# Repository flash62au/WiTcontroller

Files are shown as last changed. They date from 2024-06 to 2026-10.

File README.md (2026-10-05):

# WiTcontroller

A WiTcontroller is a simple DIY, handheld controller that talks to a WiThrottle Server (JMRI, DCC-EX EX-CommandStation, Digitrax LnWi and many others) using the WiThrottle protocol to control DCC model trains. 

> [See full change log/ version history](change_log.md)

---

## Why WiTcontroller?

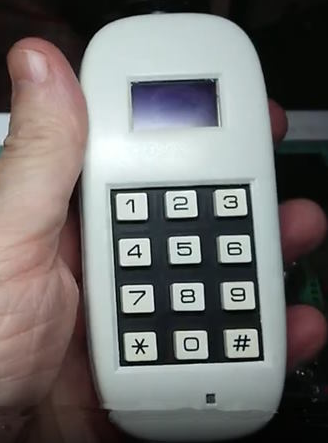
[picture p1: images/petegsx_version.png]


There are a number of excellent DIY DCC controllers available, but most require a lot of components and a lot of soldering.  I wanted to create the simplest possible controller so that it would be as easy (as possible) to make one.

In its basic form, the WiTcontroller uses only four components plus a battery.  You can even put it together without soldering, though I don't recommend that for long term use.

While the basic form is simple, the design is flexible and you can add several additional components if you wish.

[See a video of it in use here.](https://youtu.be/RKnhfBCP_SQ)  
[and another...](https://www.youtube.com/watch?v=1w7H2OvP8Jg) (from GingeAngles)
[and another...](https://youtu.be/69rTwZ4NM7E?si=bjXsFOhbpBvZsjaS) (from Sumner)

## The name

*WiTcontroller* is a contraction of 'WiThrottle Controller' as it uses the WiThrottle Protocol for communications with the server.  I pronounce it as 'Wit Controller', but you can pronounce it however you like.😊

> [!NOTE]
>
> * 'WiThrottle' is a trademark owned by Brett Hoffman. It is also an iOS app developed by Brett Hoffman.
> * The 'WiThrottle protocol' is a communications protocol developed by Brett Hoffman.  It is used by **WiTcontroller**, JMRI, Engine Driver, the WiThrottle app plus a number of other apps and DCC Command Stations. References in this document to a 'WiThrottle Server', refer to any server that can communicate using the 'WiThrottle protocol'.
 
---

## Index / Contents

* [Prerequisites](#prerequisites)
* [Building](#building)
* [Loading the Code](#loading-the-code)
* [Using WiTcontroller](#using-witcontroller)
* [Allowed Actions](#allowed-assignments-for-the-0-9-keys-andor-additional-buttons)
* [Options and Extras](#options-and-extras)
* [Contact Me](#contact-me) <br/> <br/>
* [Modifying the code](#modifying-the-code)
* [Change Log](#change-log)

<br/>
<hr style="border: none; height: 4px; background-color: #007bff; border-radius: 2px;">

## Prerequisites

1. Some basic soldering skills.

    The components will work if just plugged together using jumpers, but they take a lot of space that way, so soldering them together is advised to make it more hand held.

2. Loading the code (sketch) requires downloading of one of the IDEs, this sketch, the libraries, etc. so some experience with Arduinos is helpful, but not critical.

3. A WiThrottle Server to connect to. WiTcontroller will work with any WiThrottle Server. e.g.

    * **JMRI**
    * **DCC-EX EX-CommandStation**
    * **MRC WiFi**
    * **Digitrax LnWi**
    * **NCE WiFiTrax**
    * and others

    Note that there seems to be an issue with the **YaMoRC Command Station** that I am still working on.  See the notes for the DEFAULT_HEARTBEAT_PERIOD define below.

<br/>
<hr style="border: none; height: 4px; background-color: #007bff; border-radius: 2px;">

## Building

### Required Components

1. **WeMos Lite LOLIN32**  (ESP32 Arduino with LiPo charger) ([Example](https://www.ebay.com.au/itm/284800618644?hash=item424f709094:g:-soAAOSwHslfC9ce&frcectupt=true)) 

    Note: *Any ESP32 will work but the pinouts may need to be adjusted, and a separate LiPo charger may be required*

> [!CAUTION]
> I have reports of some of the versions of this board with the USB-C connectors having problems with the WiFi.  Some are clearly fine, but others are not. I am still investigating this, but I would recommend avoiding the USB-C version for now.

2. **3x4 Keypad**  ([Example](https://www.jaycar.com.au/12-key-numeric-keypad/p/SP0770?pos=2&queryId=20aedf107668ad42c6fe1f8b7f7a9ca7)) 

    Notes:

    * Alternately a 4x4 keypad can also be used (see optional components below)
    * Different keypad manufacturers may arrange the pins on the base of the keypad differently.*** See notes in the [Default Pins for the keypads](#default-pins-for-the-keypads) section below.

3. **KY-040 Rotary Encoder Module** ([Example](https://www.aliexpress.com/item/1005003946689694.html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)) 

    Notes:

    *The **EC11 rotary encoder** will also work, but requires a small configuration change in ``config_buttons.h`` (see below)*

4. **OLED Display** 0.96" 128x64 I2C IIC SSD1306 ([Example](https://www.ebay.com.au/itm/273746192621?ssPageName=STRK%3AMEBIDX%3AIT&_trksid=p2060353.m2749.l2649))

    Notes:

    * *The code for the one of the common 1.3" displays is also included (see below).*
    * *Some OLED displays up to 2.4 inch will also work (see below)*

5. **Polymer Lithium Ion Battery LiPo** 400mAh (or larger) 3.7V 502535 JST Connector. ([500mAh Example](https://www.ebay.com.au/itm/133708965793?hash=item1f21ace7a1:g:tlwAAOSwfORgYqYK)) 

    Notes:

    * Any capacity battery will work. A 400mAh will give about 6 hours of run time.*
    
> [!CAUTION]
> *I have found that some batteries come with the positive and negative leads the other way around to the terminals on the ESP32.* **Check they are correct before plugging it in!** <br/> <br/> The polarity of the battery is easy to swap, by getting a knife blade under the small tabs on the plastic connector and pulling each male socket out. Take extreme care. **DO NOT SHORT THE TERMINALS.**

6. **A Case to put it in**. Links to a few different designs are below, but any box will do. My case was 3d printed for me (see below).

7. **A Knob** ([Example](https://www.jaycar.com.au/35mm-knob-matching-equipment-style/p/HK7766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))

8. **Wire** - If you plan to solder the connections, which is the recommended approach, then stranded, coloured wire is advisable.  ([Example](https://www.jaycar.com.au/rainbow-cable-16-core-sold-per-metre/p/WM4516))

### Optional Components

9. *Optional:* **A power switch**. Push button or toggle. <br/> The battery in WiTcontroller will last a week or two in deep sleep, but you may wish to add a power switch on the positive feed of the battery if you expect to leave it unused for long periods.

10. *Optional:* You can use a **4x4 keypad** instead of the 3x4 keypad. <br/> Note: You will need to make a small configuration change in ``config_buttons.h`` for this to work correctly.

11. *Optional:* Up to eleven (11) additional **push buttons** can be added directly to the ESP32, each with their own independent commands. ([Example](https://www.jaycar.com.au/red-miniature-pushbutton-spst-momentary-action-125v-1a-rating/p/SP0710))

12. *Optional:* **A 1.3" or 2.4" OLED Display** (128x64) can be used instead of the 0.96" OLED Display 128x64 ([Example](https://www.aliexpress.com/item/32683094040.html?spm=a2g0o.order_list.order_list_main.110.25621802jRBB7y)) Note: You will need to make a minor change in the config file for this to work correctly.

13. *Optional:* Though not recommended, it is possible to use a **Potentiometer** instead of the Rotary Encoder for throttle control.  The code supports it if you make the appropriate configuration changes in ``config_buttons.h``.   However this has had only limited testing. <br/> This is documented to some degree in [config_buttons_example.h](config_buttons_example.h) if you wish to try it.

### Pinouts

*Standard Configuration Pinouts*  <br/> This is the simplest form of the WiTcontroller
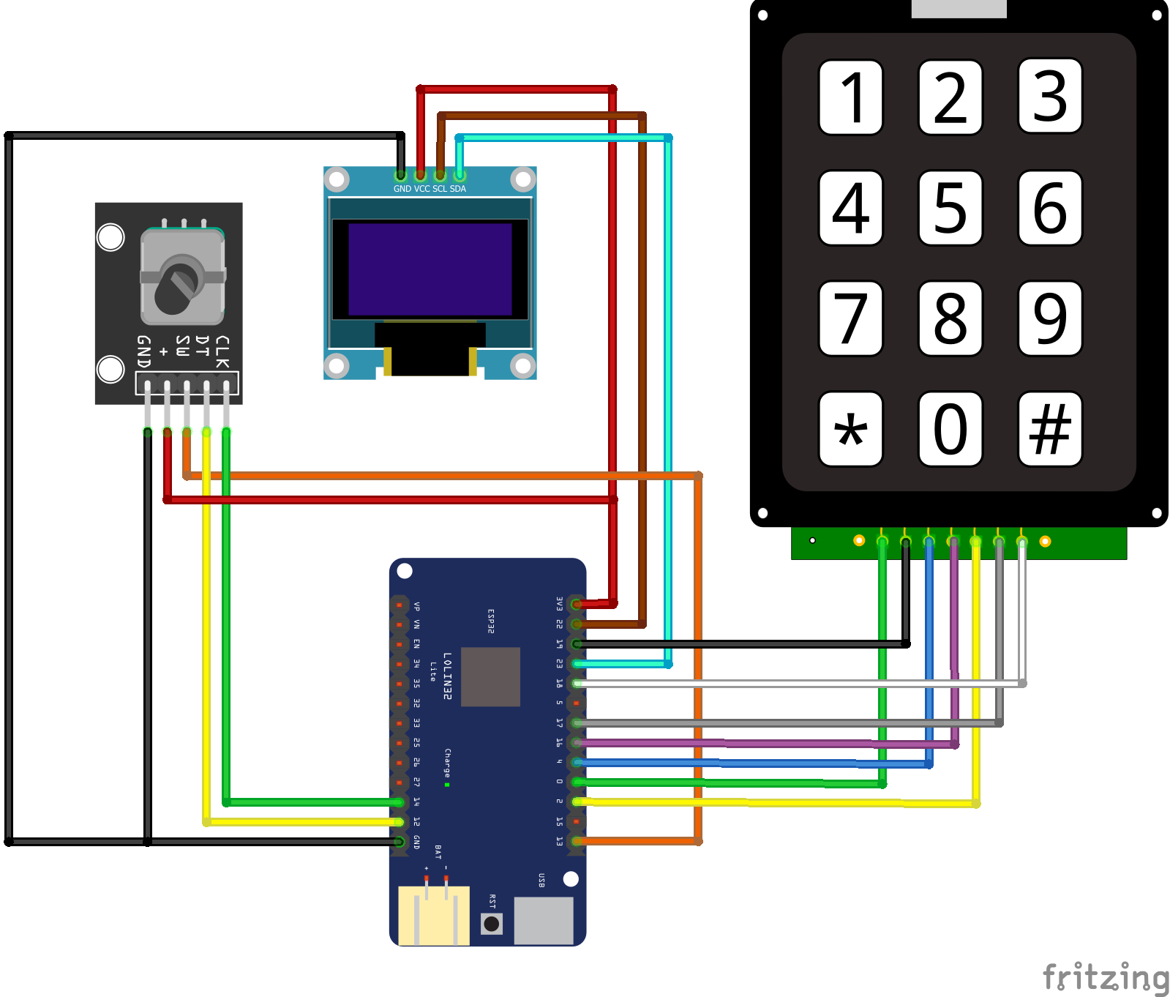
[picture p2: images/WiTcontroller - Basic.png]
Assembly diagram


*Pinouts for Optional Additional Buttons*
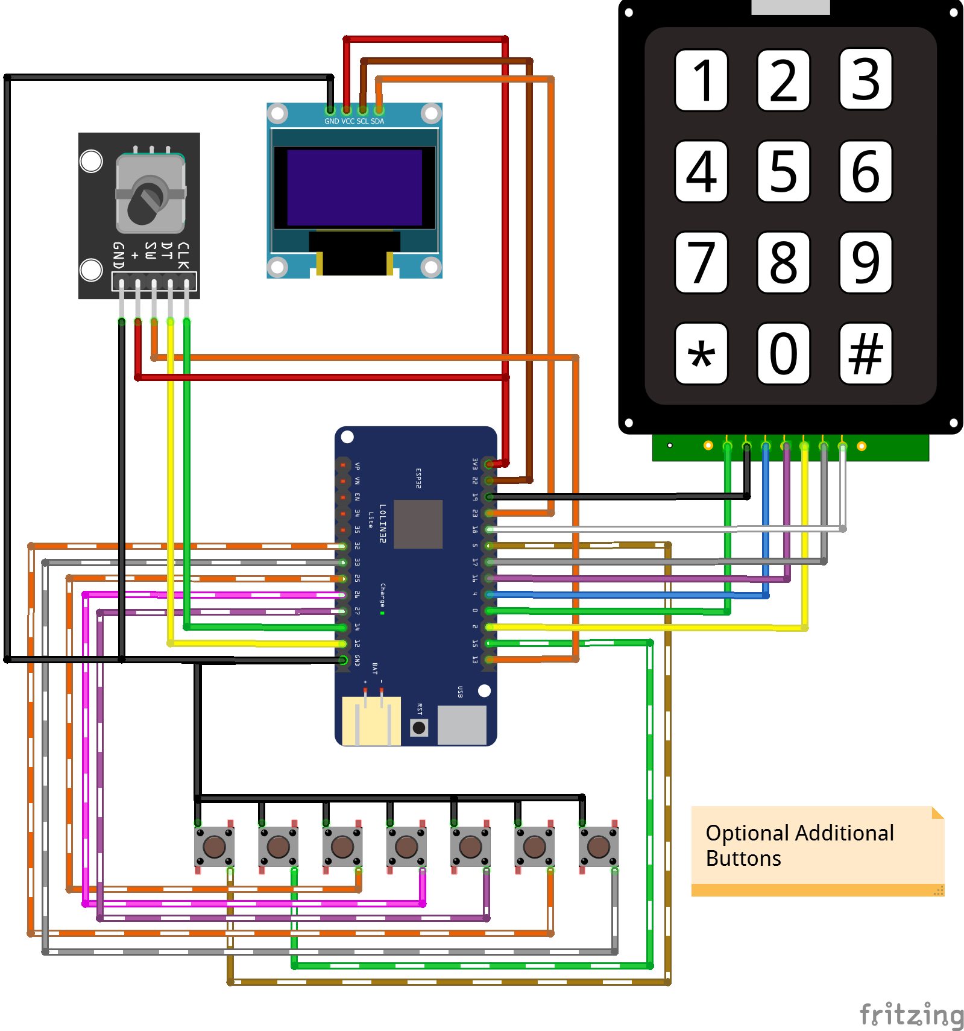
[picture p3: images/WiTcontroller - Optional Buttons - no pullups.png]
Assembly diagram - Optional Additional Buttons


*Pinouts for Optional Additional Buttons - With Pullups*
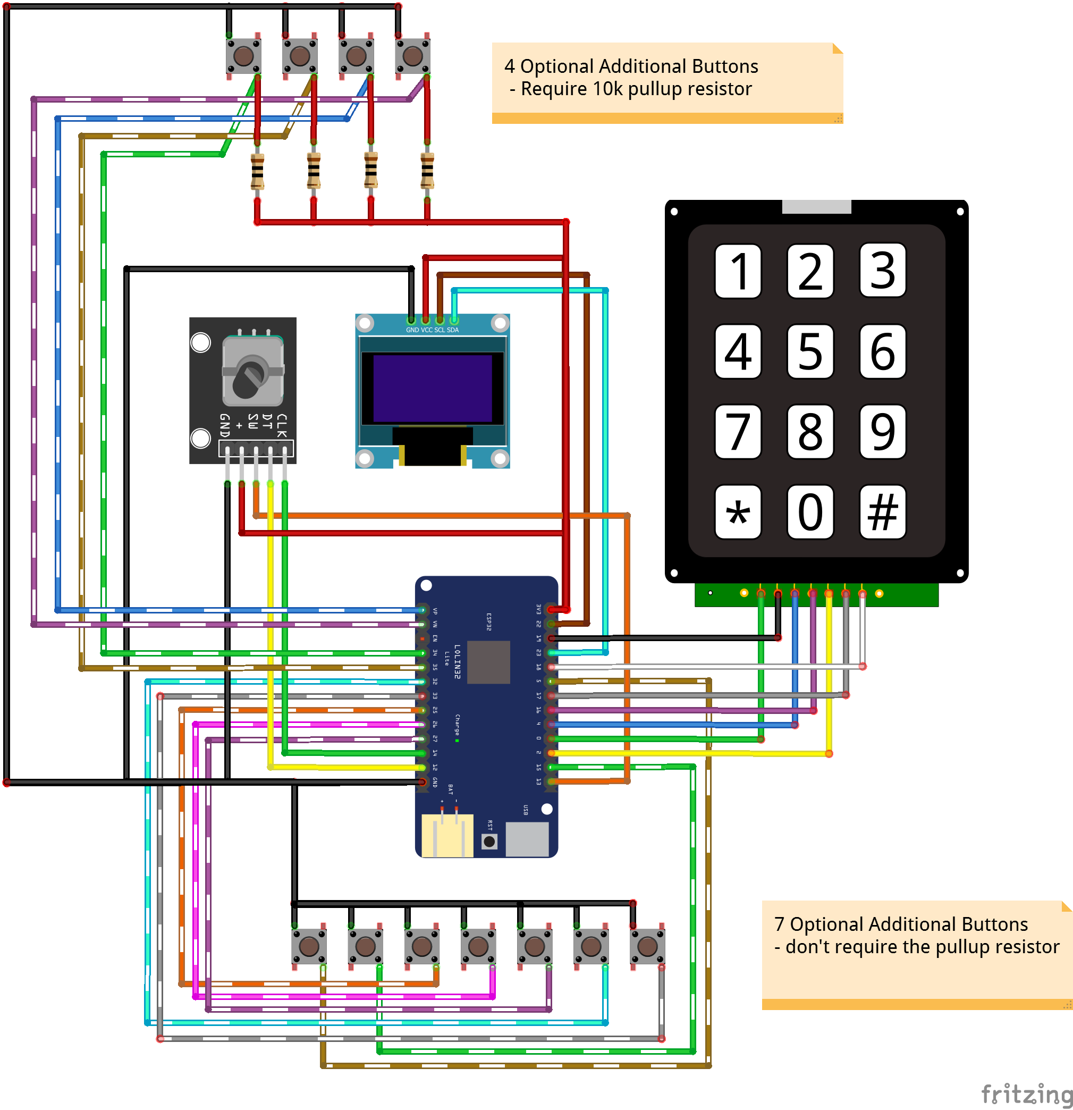
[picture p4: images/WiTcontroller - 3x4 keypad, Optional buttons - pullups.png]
Assembly diagram - Optional Additional Buttons - With Pullups


*Pinouts for Optional 4x4 keypad and Additional Buttons - without pullup resistors*
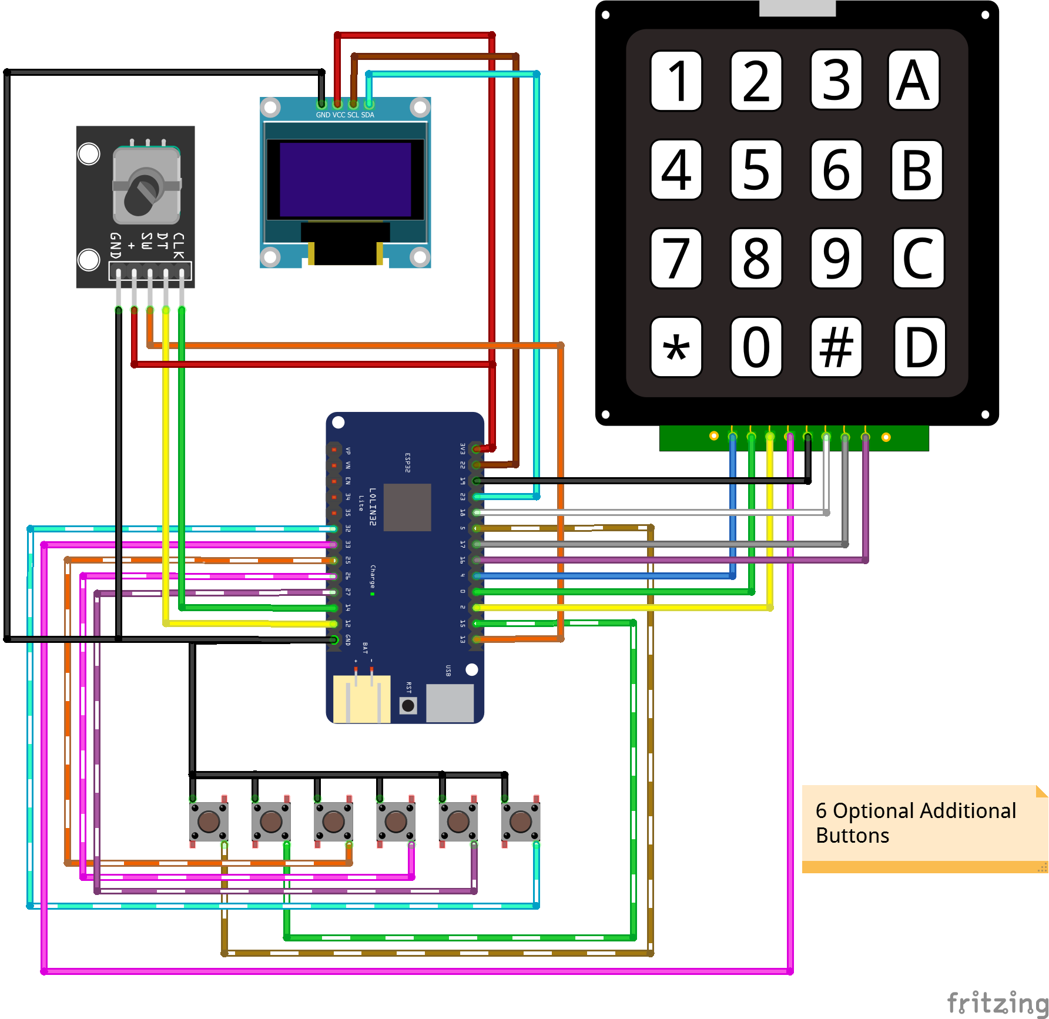
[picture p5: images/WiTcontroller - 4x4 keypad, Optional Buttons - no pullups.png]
Assembly diagram - 4x4 keypad and Optional Additional Buttons


*Pinouts for Optional Battery Monitor and Additional Buttons*
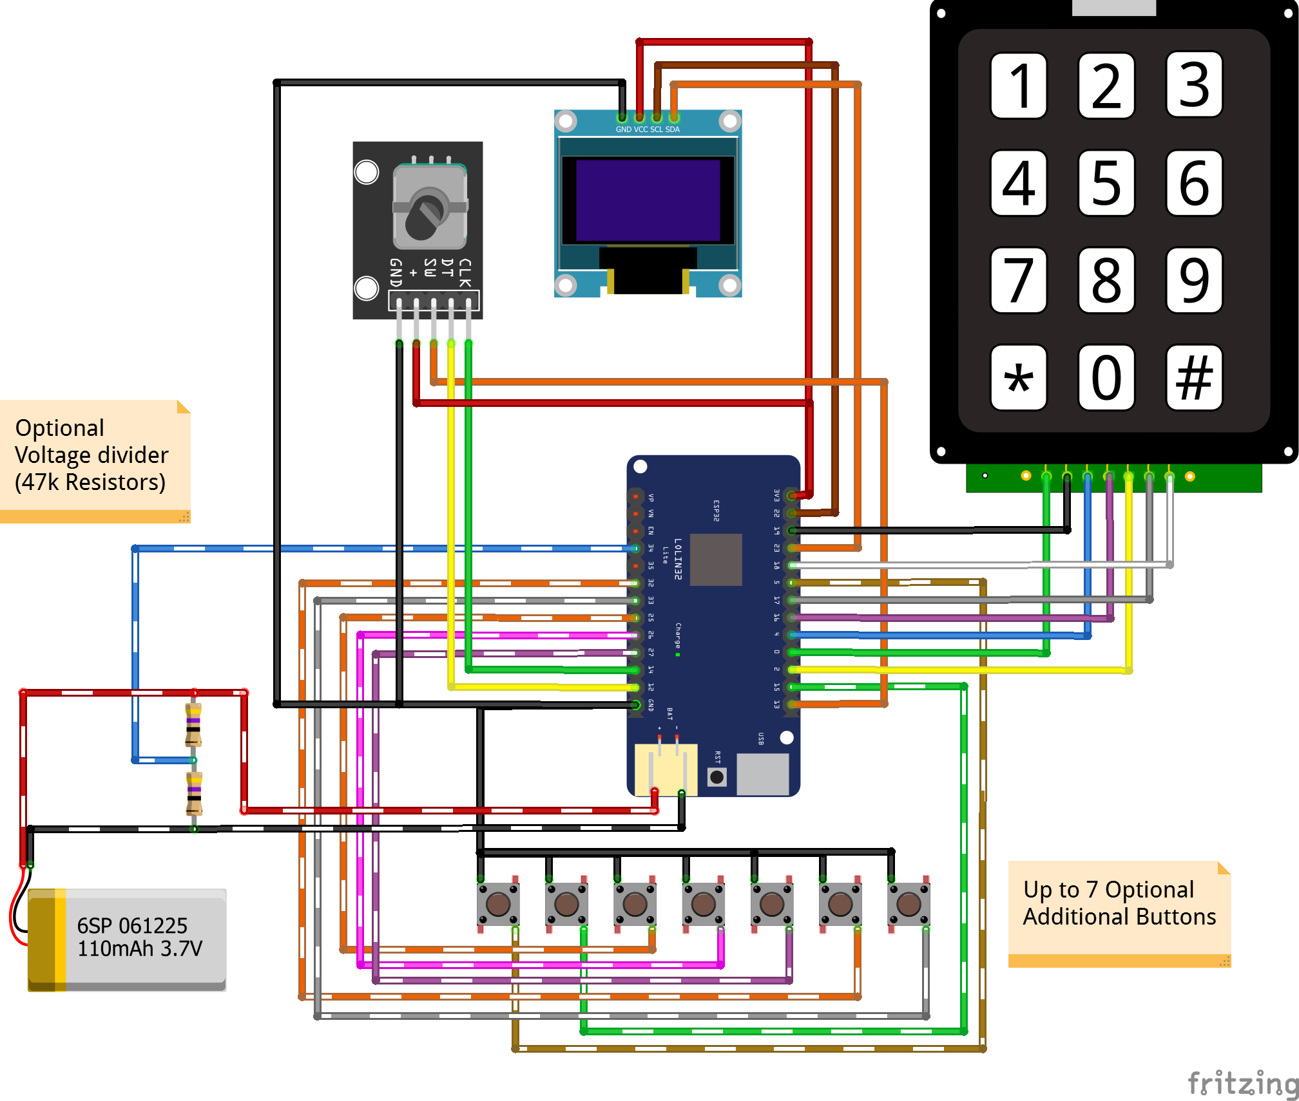
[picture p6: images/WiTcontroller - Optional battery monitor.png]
Assembly diagram - Optional Battery Monitor and Additional Buttons


> [!WARNING]
> *Different keypad manufacturers may arrange the pins on the base of the keypad differently to the examples above.* <br/> See notes in the [Default Pins for the keypads](#default-pins-for-the-keypads)  section below.

---

### Default Pins

#### Default ESP32 and WiTcontroller pins

<details>

<summary>Click to expand to see a table of the default pinouts</summary>

```
         3x4    4x4    OLED Encoder  Additional   Battery
    Pin Keypad Keypad                  Buttons     Test
     0    C1     C1                             
N/A  1                                       
     2    C2     C2                             
N/A  3                                     
     4    C0     C0                             
     5                                  AB0     
N/A  6                                      
N/A  7                                      
N/A  8                                      
N/A  9                                      
N/A 10                                       
N/A 11                                       
    12                        DT               
    13                        SW               
    14                        CLK               
    15                                  AB1     
    16     R3     R3                             
    17     R2     R2                             
    18     R1     R1                             
    19     R0     R0                             
N/A 20                                       
N/A 21                                       
    22                  SLC                     
    23                  SDA                     
N/A 24                                       
    25                                  AB2     
    26                                  AB3     
    27                                  AB4     
N/A 28                                       
N/A 29                                       
N/A 30                                       
N/A 31                                       
N/A 32                                  AB5     
    33          C3                      AB6     
    34                                  AB7 *        BT
    35                                  AB8 *     
VP  36                                  AB9 *     
N/A 37                                       
N/A 38                                       
VN  39                                  AB10*     

* Requires an external pullup resistor
```
</details>

<br />

#### Default Pins for the keypads

<details>

<summary>Click to expand to see a table of the Default Pins for the keypads</summary>

```
3x4 Keypad - Left to Right    4x4 keypad - Left to Right
 C1 PIN 0                      C0 PIN 4
 R0 PIN 19                     C1 PIN 0
 C0 PIN 4                      C2 PIN 2
 R3 PIN 16                     C3 PIN 33
 C2 PIN 2                      R0 PIN 19
 R2 PIN 17                     R1 PIN 18
 R1 PIN 18                     R2 PIN 17
                               R3 PIN 16

Cx = Column x      Rx = Row x

WARNING:
Different keypad manufacturers may arrange the pins on the 
base of the keypad differently to those listed above.
So it is important to make sure the pins on the keypad are 
correctly identified and adjusted as needed.

```
 
</details>

---

### Case

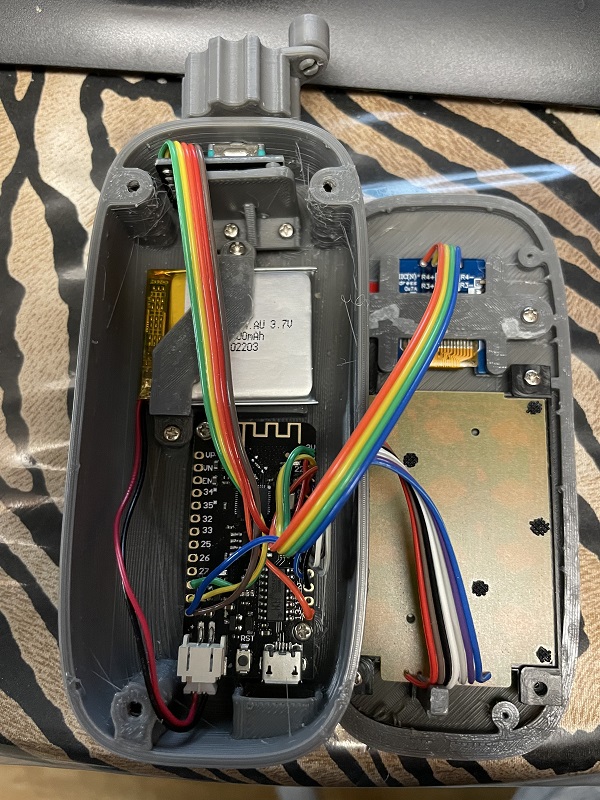
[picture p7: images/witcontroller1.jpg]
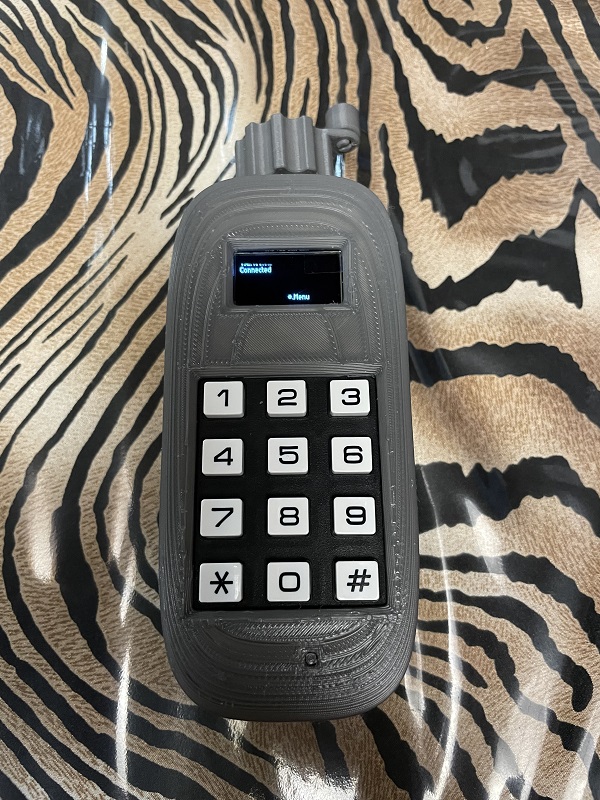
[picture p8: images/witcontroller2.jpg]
 

My case was 3D Printed for me by peteGSX (See the [Thingiverse.](https://www.thingiverse.com/thing:5440351) )

* The 3x4 keypad petGSX designed the case for came from Jaycar and is slightly narrower than the one you see in the 'deconstructed' view in the video above.
* The case requires about a dozen M2x4mm screws

---

### Variations

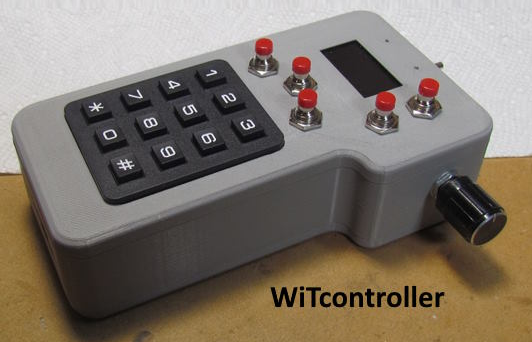
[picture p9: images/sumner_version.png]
 <br/>
See [*sumner* version](https://1fatgmc.com/RailRoad/DCC/WiTcontroller-Index.html).

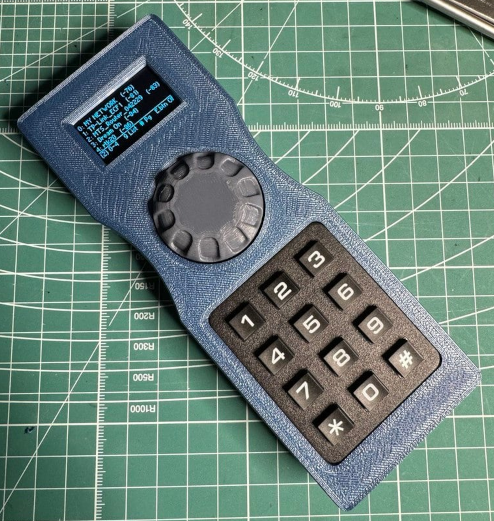
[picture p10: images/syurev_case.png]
 <br/>
syurev version. See [Thingiverse](https://www.thingiverse.com/thing:6541187) or [cults3d](https://cults3d.com/en/3d-model/gadget/case-for-dccexcontroller-witcontroller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)

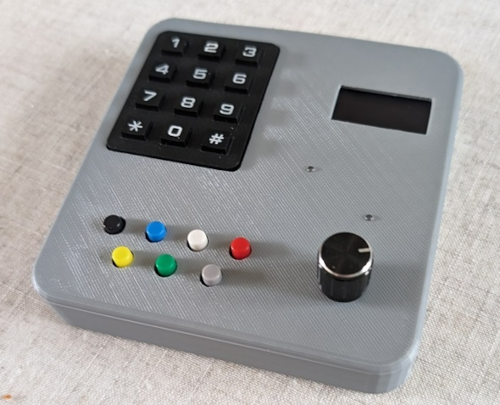
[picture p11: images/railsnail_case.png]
 <br/>
Railsnail version. See [RMweb](https://www.rmweb.co.uk/forums/topic/186297-project-a-witcontroller-wireless-throttle-to-control-my-dcc-ex-commandstation/).

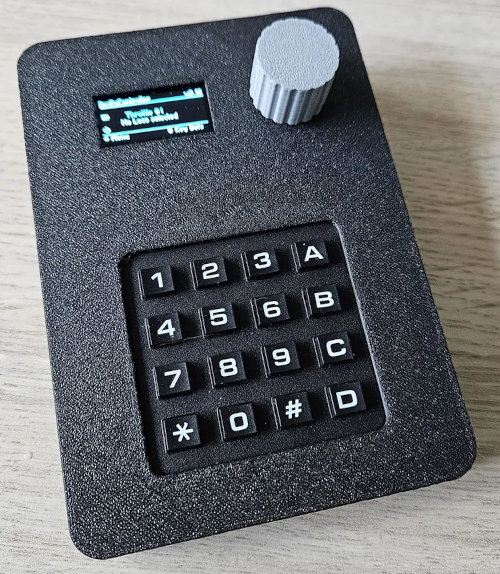
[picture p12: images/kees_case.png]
 <br/>
kees version. See [printables](https://www.printables.com/model/907658-dccexcontroller-witcontroller).

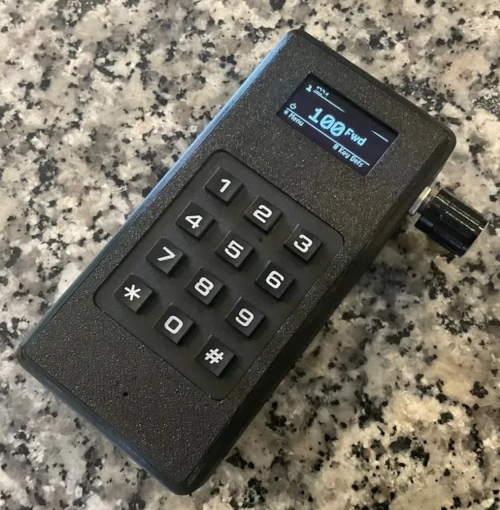
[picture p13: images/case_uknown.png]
 <br/>
Unknown author. See [Thingiverse](https://makerworld.com/en/models/819825).

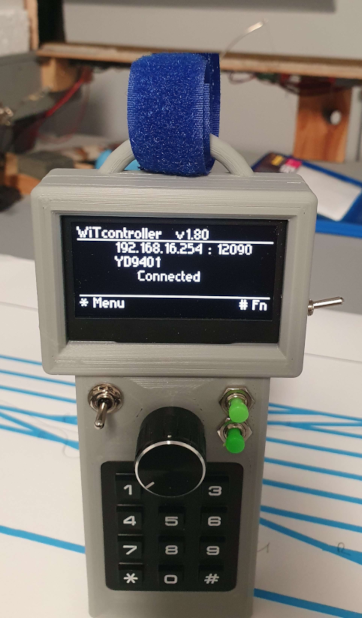
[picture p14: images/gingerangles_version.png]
 <br/>
*gingerangles* version with 2.4 inch screen...
gingerangels can be contacted on the DCC-EX Discord server.
[Discord Invite](https://discord.gg/8ghsjsBup8) - 
[specific message](https://discord.com/channels/713189617066836079/735156882511102033/1316646832297742380)

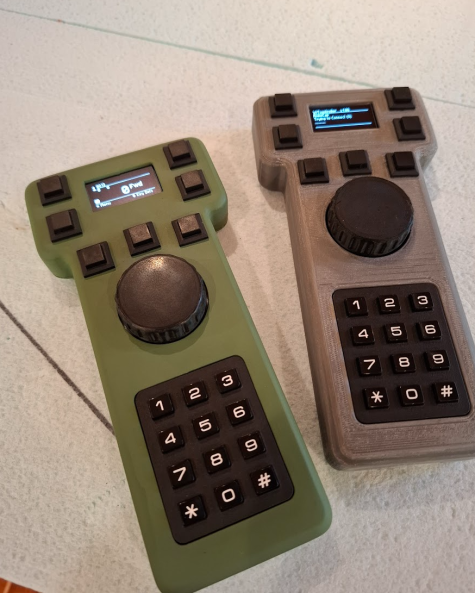
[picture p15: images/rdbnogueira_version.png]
 <br/> 
rdbnogueira version. See [Thingiverse](https://www.thingiverse.com/thing:6956982)

 <br/>
David Virgo's version using the EC11 encoder. See [GitHub](https://github.com/dvirgo62/Printed-case-for-witcontroller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)

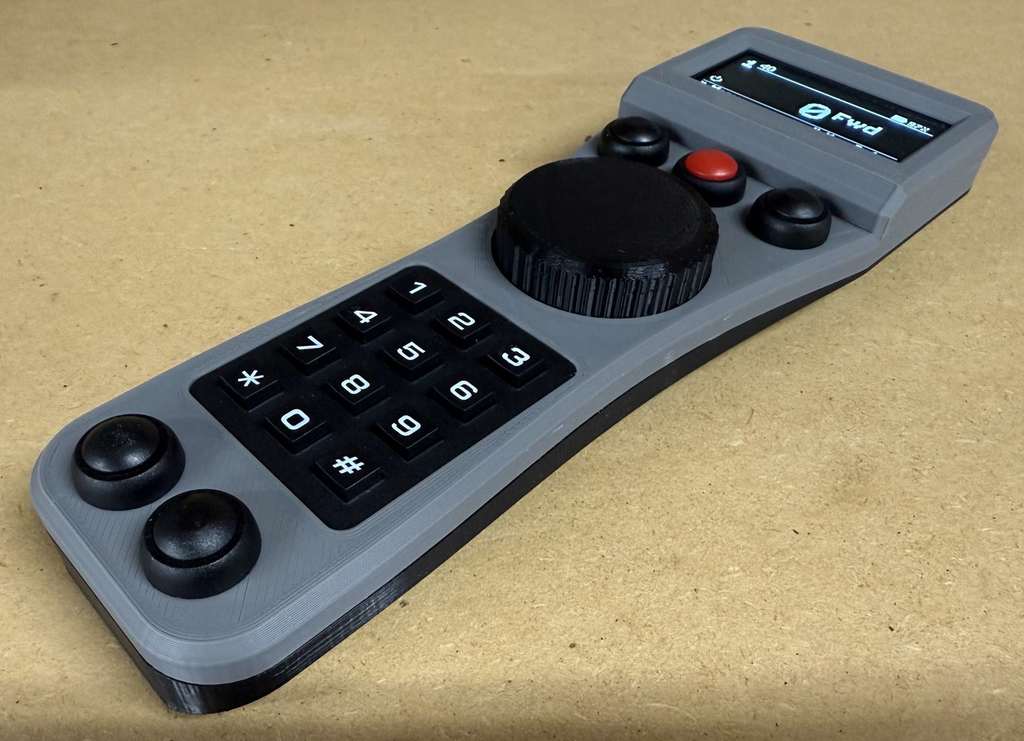
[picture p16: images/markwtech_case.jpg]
 <br/> 
markwtech version. See [Thingiverse](https://www.thingiverse.com/thing:7029069)

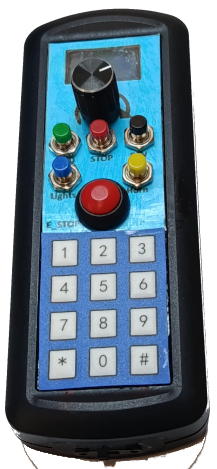
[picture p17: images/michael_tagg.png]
 <br/> 
Michael Tagg version.

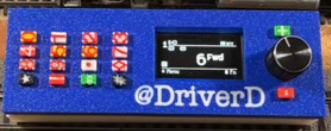
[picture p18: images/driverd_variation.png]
 <br/> 
DriverD's variation of the design. See [YouTube](https://youtu.be/i4kLNncoFLA?si=Nli4HzZWGFATpnhh)

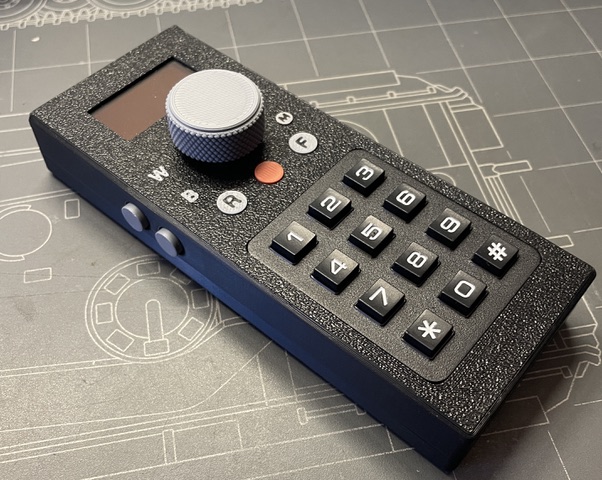
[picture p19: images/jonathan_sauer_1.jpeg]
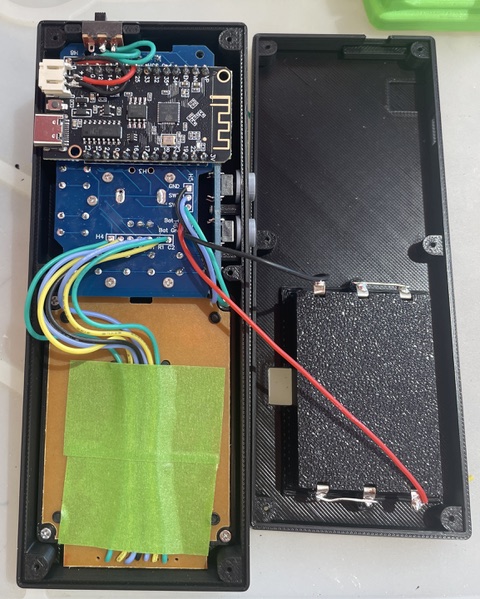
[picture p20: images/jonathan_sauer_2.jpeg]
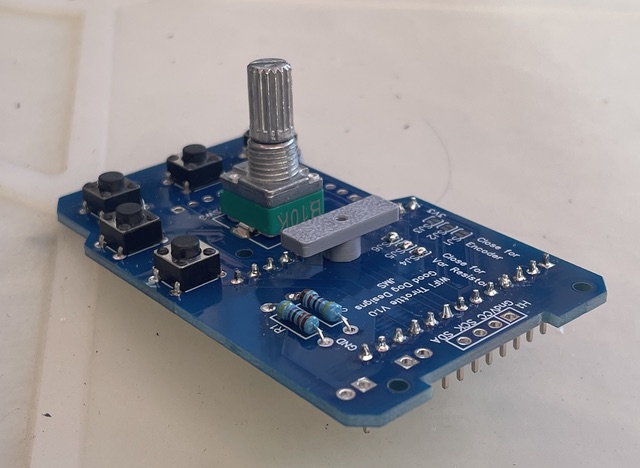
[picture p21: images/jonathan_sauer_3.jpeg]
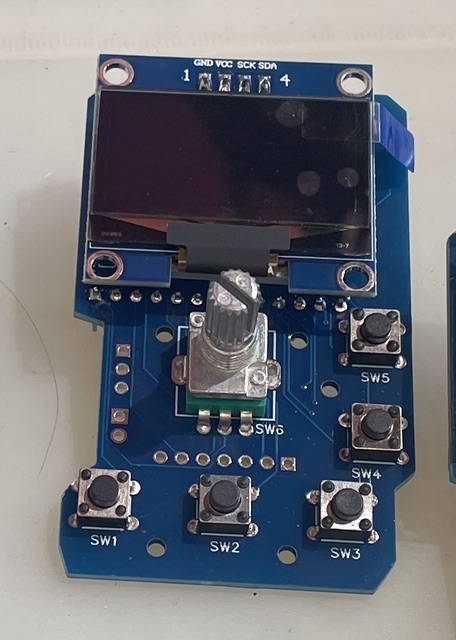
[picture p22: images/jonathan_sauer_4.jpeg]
    <br/>Jonathan Sauer's custom PCB version.

---

Some videos:

* https://youtu.be/RKnhfBCP_SQ
* https://www.youtube.com/shorts/1w7H2OvP8Jg
* https://www.youtube.com/watch?v=Ga_80A6LwCI (Full assembly video by DriverD)
* https://youtu.be/i4kLNncoFLA?si=bzF-ETGZtZM3IBoa (A variation by DriverD)
* https://www.youtube.com/watch?v=cClRS21x_cc&t=4s  - A deconstructed view of a WiTcontroller in action

---

And for a very different take on what is possible by extending the design, have a look at: https://1fatgmc.com/RailRoad/DCC/HandCab-Index.html and at: https://1fatgmc.com/RailRoad/DCC/PhL%20Industries%20Cab%20Index.html

<br/>
<hr style="border: none; height: 4px; background-color: #007bff; border-radius: 2px;">

## Loading the code

The instructions below are for using the **Arduino IDE** and **GitHub Desktop**.

**Visual Studio Code (VSC)** can be used instead of the Arduino IDE, and is actually my preferred IDE, but no instructions are included here.  Contact me if you need assistance with VSC.

1. Download the **Arduino IDE**.
    * Available from  https://support.arduino.cc/hc/en-us/articles/360019833020-Download-and-install-Arduino-IDE

2. Download the **esp32** *boards* in the Arduino IDE.
    * Add the esp322 support with the following instructions:  (See here for detailed instructions:  https://randomnerdtutorials.com/installing-the-esp32-board-in-arduino-ide-windows-instructions/)
        * In the Arduino IDE, go to *File* > *Preferences*
        * Enter the following into the 'Additional Board Manager URLs' field:  https://dl.espressif.com/dl/package_esp32_index.json
    * Then Use the *Boards Manager* in the *Arduino IDE* to install the esp32 board support
        * *Tools* > *Board* > *Boards Manager*
        * Search for "esp32" by Expressive Systems.  Install version 3.2.0 or later. Version 3.3.0 is recommended.  (Later versions work, but go back to this 3.2.0 if you have problems.) (Eralier versions work, but 3.2.0 or later is required if you want to use 2.4gHz WiFi channels greater than 10. See notes below. )

3. Download or clone *this* repository. <br/> (Note: if you 'clone' initially, it is easier to receive updates to the code by doing a 'fetch' subsequently.  See Notes below.)
    * Option - Clone - **First Time**  ***Recommended***
       * Install *GitHub Desktop* from https://desktop.github.com/
       * Create a free account on GitHub and authorise the app to allow it to connect top GitHub
       * Select *file* -> *Clone Repository* - or 'Clone an repository from the internet' from the welcome page then select the 'URL' tab
       * Enter *https://github.com/flash62au/WiTcontroller* as the URL
       * Select a local folder to install it.  The default folder for the Arduino usually looks like "...<username>\Documents\Arduino\". (This is a good but not essential place to put it.)
       * Click *Clone*
       * **Subsequently**  (Anytime after the first 'clone')
         * click *Fetch Origin* and any changes to the code will be bought down to you PC, but your `config_buttons.h` and `config_network.h` will not be touched.
    * Option - Download ***Not Recommended***
       * Open *https://github.com/flash62au/WiTcontroller*
       * Click the green "Code" button and select download zip
       * Extract the zip file to a local folder.  The default folder for the Arduino usually looks like "...<username>\Documents\Arduino\". This is a good, but not essential, place to put it.

4. Load the needed libraries to your PC. <br/> These *MUST BE* loaded from the *Library Manager* in the *Arduino IDE*. 
    * *U8g2lib.h* -  Search for "U8g2".   Install version 2.35.30 or later. <br/> (later versions should work, but go back to this 2.35.30 if you have problems.)
    * *AiEsp32RotaryEncoder.h* - search for "Ai Esp32 Rotary Encoder".  Install Version 1.6
    * *Keypad.h* - Search for "Keypad" by Mark Stanley.  Install version 3.1.1 or later. <br/> (later versions should work, but go back to this 3.1.1 if you have problems.)
    * *WiThrottleProtocol.h* - Search for "WiThrottleProtocol" (not "WiThrottle").  Install the latest version available. <br/> (see *version notes* below for which versions of WiTcontroller require which versions of the library.)

      Note: <br/> **DO NOT** download these libraries *directly*. Use the *Library Manager*. <br/> **DO NOT** put them in the WiTcontroller folder.

5. These should have been automatically installed when you downloaded the esp32 boards. <br/> *YOU SHOULD NOT NEED TO DO ANYTHING SPECIFIC TO GET THESE*
    * *WiFi.h*  - https://github.com/espressif/arduino-esp32/tree/master/libraries/WiFi
    * *ESPmDNS.h* - https://github.com/espressif/arduino-esp32/blob/master/libraries/ESPmDNS
    * *Preferences.h*

      Notes: <br/> **DO NOT** download these libraries *directly*. Use the *Boards Manager*. <br/> **DO NOT** put them in the WiTcontroller folder. <br/> These libraries do not appear in your list of libraries, but will be available to use regardless. (The files are actually buried away in a subfolder of the ESP32 Boards library.)

6. Copy and rename the two example config files. <br/> You will need to use a *File Manger* type of app on the PC to do this.
    * Copy ``config_network_example.h`` to a new file ``config_network.h``
    * Copy ``config_buttons_example.h`` to a new file ``config_buttons.h``

      Alternately, you can use the experimental [button configuration generator page](https://flash62au.github.io/WiTcontroller/config_buttons_generator.html) to create the ``config_buttons.h`` for you. And the experimental [network configuration generator page](https://flash62au.github.io/WiTcontroller/config_network_generator.html) to create the ``config_network.h`` for you.

      Note: <br/> These new files are not included in the download, so that you can personalise your configuration without fear that your configurations will be overridden if you update (download again) the WiTcontoller code.

7. Open the Arduino IDE and **THEN** find and open the ``WiTcontoller.ino`` file.

      Note: <br/> *If you open the file **from** the IDE*, rather then opening it from a File Manager, will automatically open *all the files in the WiTcontroller folder* in the IDE.

      Whereas, *if you open it from a File manger app* (by double clicking on it) only the file you selected will open.

8. Edit your personal ``config_network.h`` file.
    * Edit it to include the network SSIDs you want to use.  (Not essential, but entering passwords via the encoder is tedious.)

9. Edit your personal ``config_buttons.h`` file.
    * Optionally, edit this to change the mapping of the keypad buttons to specific functions.
    * Optionally, edit this to configure the additional buttons (if you have included them) to specific functions.
    * Optionally, edit this to change if you want the function buttons to display when you press #, instead of the default of showing the Key Definitions
    * Optionally, change the language/localisation. <br/> See the [Languages / localisation](#languages-and-localisation) section below.

10. Upload the sketch.  
    * Select the board type as ``WEMOS LOLIN32 Lite`` in the *Arduino IDE*.
    * Connect the board via USB and select the appropriate port in the *Arduino IDE*.
    * Click ``Upload`` **-->**

### Version Notes

<details>

<summary>Click to expand</summary>

* WiTcontroller version 1.83 includes a new way to add additional buttons. (see below) The old way will continue to work, but conversion to the new format is recommended. <br/> This change allows up to a total of 11 additional buttons, but some of the extra pins may be in use for the 4x4 keypad, the battery test, etc.
* WiTcontroller version 1.82 or later requires WiThrottleProtocol version 1.1.26 or later.
* WiTcontroller version 1.73 or later is recommended to use WiThrottleProtocol version 1.1.25 or later to address a bug in heartbeat send, but only seen with JMRI WiThrottle .
* WiTcontroller version 1.66 or later requires WiThrottleProtocol version 1.1.24 or later.
* WiTcontroller version 1.65 or later requires WiThrottleProtocol version 1.1.23 or later.
* WiTcontroller version 1.57 or later requires WiThrottleProtocol version 1.1.20 or later for the E_STOP and E_STOP_CURRENT_LOCO to work correctly.
* WiTcontroller version 1.45 or later requires WiThrottleProtocol version 1.1.14 or later.
* WiTcontroller version 1.41 or later requires WiThrottleProtocol version 1.1.12 or later.
* WiTcontroller version 1.39 or later requires WiThrottleProtocol version 1.1.11 or later.
* WiTcontroller version 1.38 or later requires WiThrottleProtocol version 1.1.10 or later.
* WiTcontroller version 1.35 or later requires WiThrottleProtocol version 1.1.7 or later.
* WiTcontroller version 1.33 or later requires WiThrottleProtocol version 1.1.6 or later.
* WiTcontroller version 1.19 - 1.32 requires WiThrottleProtocol version 1.1.3 - 1.1.5 or later.
* WiTcontroller version 1.06 or later requires WiThrottleProtocol version 1.1.2 or later.
* WiTcontroller version 1.01 or later requires WiThrottleProtocol version 1.1.0 or later.
* WiTcontroller version 0.10 or later requires WiThrottleProtocol version 1.0.3 or later.
* The *WiFi.h* and *ESPmDNS.h* libraries were automatically installed for me when I installed the esp32 boards, however it is possible that you may need to install them manually, but this is seriously not recommended.
* Later versions of the ESP board support are available and do appear to work, but if you have difficulties version 2.0.11 and 1.0.6 appear to be stable.
* Later versions of the libraries generally should work, but if you have difficulties use the versions listed above.
* To get the WiTcontroller sketch I recommend using either the git command line, or the far more friendly 'GitHub Desktop' app.  See instructions above.
* If you receive and error related to Python, and you are on MacOS 12 and above please edit the platform file, change from python to python3 as follows; preferences->user/path/arduino/packages/hardware/esp32/version/platform.txt and edit the line that looks as follows:tools.gen_esp32part.cmd=python3 "{runtime.platform.path}/tools/gen_esp32part.py"

</details>

<br/>
<hr style="border: none; height: 4px; background-color: #007bff; border-radius: 2px;">

## Using WiTcontroller

### Be aware of...

#### WiFi limitations

The ESP32 *cannot use the 5gHz* frequencies.  It is limited to the 2.4gHz  frequencies.

Using 2.4gHz Wifi channels beyond 10 (11-13) is problematic. I have added an experimental set of definitions in [config_network_example.h](config_network_example.h) that allow you to set the country code.  In theory this will allow the use of the additional channels, but requires the use the version 3.2.0 (or later) of the ESP32 board library.  This has had only minimal testing.

## Definitions and Explanations

*WiTcontroller* is deliberately described as a "controller" not a "throttle".  

A "Throttle" can control only one train, which may be one loco, or more than one loco in consist/MU.

*WiTcontroller*, as a "controller", **contains up to six (6) "throttles"**. Each of which can control any number of locos in consist/MU. You can swap between throttles at will (``keypad 5``) to select which locos/consists/MUs you are manipulating at any given time. While you can only manipulate one loco/consist/MU at a time, the others continue running at the setting you last gave them.

### Features

**Currently functioning:**

WiTcontroller:

* Provides a list of discovered SSIDs with the ability to choose one. When you select one:
  * If it is one in your specified list (in the sketch), it will use that specified password
  * If it is a DCC-EX EX-CommandStation in Access Point (AP) mode, it will try to guess the password.
  
    *Warning!* prior to version 1.108 WiTcontroller assumes that it will be the default password for EX-CommandStations. If you have changed the password it will fail to connect unless you have the SSID *and correct password* listed in `config_network.h`.  

    From version 1.108 it will try to connect to a DCC-EX EX-CommandStation with the 'guessed' password on the first attempt.  Then, if it fails to connect, it will ask for the password on the second attempt.

    Note that it will only try to guess the EX-CommandStation password if the SSID name is in the default form of "DCCEX_xxxxxx". Where xxxxxx is part of the MAC address of the device.
  * Otherwise it will ask to enter the password (Use the rotary encoder to choose each character and the encoder button to select it.  ``*`` = backspace.  ``#`` = enter the password.)

    Any/all passwords entered this way will be stored in non-volatile memory and will be retrieved on the next attempt to connect, then WiTcontroller will allow you to edit or confirm it
* Optionally provides a list of SSIDs with the specified passwords (in the sketch) to choose from
* Auto-connects to the first found WiThrottle Protocol Server if only one found, otherwise:
  * Asks which server to connect to
  * If none found will ask to enter the IP Address and Port
  * Guesses the WiThrottle IP address and Port for DCC-EX EX-CommandStations in Access Point (AP) mode

    From version 1.111 it 'guesses' that there will be a server on 192.168.4.1:2650 if the SSID name contains "DCCEX" or "DCC-EX". (Prior version 1.111 it would only guess if the SSID name was in the default form of "DCCEX_xxxxxx".)
  * Optionally you can add a #define (a preference) to disable this auto connect feature
* Allows On-the-fly consists/MUs
  Allows assigning commands directly to the 1-9 buttons (in the sketch) (see list below)
  * This is done in ``config_button.h``
  * Latching / non-latching for the function is provided by the roster entry of the WiThrottle server
* Optionally uses a potentiometer (pot) instead of the rotary encoder
* Optional ability to assign commands directly to the 1-11 additional buttons (in the sketch) (see list below)
  * These are defined ``config_button.h``
* Provides a command **Menu** (see below for full list) including:
  * Able to select and deselect locos:
    * by their DCC address, via the keypad
      * On NCE systems, a leading zero (0) will force a long address
    * From the first 50 locos in the roster (can be increased)
  * Able to select multiple locos to create a consist
    * Able to change the facing of the additional locos in the consists/MUs (via the 'extra' menu after selection)
  * Able to activate any function (0-31)
    * Showing of the roster function labels (from the WiThrottle server if provided)
    * Quick access to the functions by pressing ``#``. Temporarily enabled via the Extras menu (or permanently enabled in ``config_button.h``)
    * Limited ability to configure which functions are sent to the first or all locos in a consist (defined in ``config_button.h``)
  * Able to throw/close turnouts/points:
    * from the address
    * from the first 50 turnouts/points in the server list
  * Able to activate routes:
    * from their address
    * from the first 50 routes in the server list
  * Set/unset a multiplier for the rotary encoder
  * Power Track On/Off
  * Disconnect / Reconnect
  * Put ESP32 in deep sleep and restart it
  * Option to switch between Single Loco and Consist/MU (Drop before Acquire)
  * Option to save the currently select locos (on multiple throttles) and have them automatically re-acquired on next connection.
  * Option to disable the heartbeat check
* Option to have up to 6 command sequences executed on connection
* Option to automatically acquire a loco if there is only one loco in the roster
* Have up to 6 throttles, each with an unlimited number of locos in consist.
  
  The default is 2 throttles, which can be increased or decreased temporarily via the Extras menu (or permanently enabled in ``config_button.h``)
* Limited dealing with unexpected disconnects.  It will throw you back to the WiThrottle Server selection screen.
* The boundary between short and long DCC addresses can be configured in ``config_buttons.h`.

  The default is that 127 and below are Short Addresses.
* The default speed step (per encoder click) can be configured in ``config_buttons.h``
* The controller will automatically shut down if no SSID is selected or entered in 4 minutes (to conserve the battery)
* Relatively easy to add/use translation files.
* Translations files for German, Italian Dutch and Chinese are included.

**ToDo:**

* Speed button repeat (i.e. hold the keypad button down)
* Deal with unexpected disconnects better
  * automatic attempt to reconnect
* Keep a list of IP addresses and ports if mDNS doesn't provide any
* Additional translation files

#### Command menu

* **0-9** keys = pressing these directly will do whatever has been configured in your ``config_buttons.h`` for them to do, or whatever is the default for that key  (see \# below)
* **\*** = Menu:  The button press following the \* is the actual command:
  * **1** = Add loco.  
    * Followed by the loco number, followed by \# to complete.  e.g. to elect loco 99 you would press '\*199\#'
    * or \# alone to show the roster   \# again will show the next page
  * **2** = release loco:
    * Followed by the loco number, followed by \# to release an individual loco.  e.g. to deselect the loco 99 you would press '\*299\#'
    * Otherwise followed directly by \#  to release all e.g. '\*2\#'
  * **3** = Toggle direction.
  * **4** = Set / Unset a 2 times multiplier for the rotary encoder dial.
  * **5** = Throw turnout/point.  
    * Followed by the turnout/point number, followed by the \# to complete.  e.g. Throw turnout XX12 '\*512\#'  (where XX is a prefix defined in the sketch)
    * or \# alone to show the list from the server   \# again will show the next page
  * **6** = Close turnout.
    * Followed by the turnout/point number, followed by \# to complete.  e.g. Close turnout XX12 '\*612\#'  (where XX is a prefix defined in the sketch)
    * or \# alone to show the list from the server
  * **7** = Set Route.
    * Followed by the Route number, followed by \# to complete.  e.g. to Set route XX:XX:0012 '\*60012\#'  (where \'XX:XX:\' is a prefix defined in the sketch)
    * or \# alone to show the list from the server   \# again will show the next page
  * **8** = Track Power On/Off.
  * **9** = Extras. Followed by...
    * 0 then \# to toggle the action the the \# key does as a direct action, either to show the direct action key definitions, or the Function labels.  
      * **1** to change the facing of locos in a consist.
      * **3** to toggle the heartbeat check.
      * **4** to increase the number of available throttle (up to 6)
      * **5** to decrease the number of available throttle (down to 1)
      * **6** to Disconnect/Reconnect.  
      * **7** to put into deep sleep
      * **8** Toggle between Single loco and Consist/MU (Drop before Acquire)
      * **9** Save the Currently selected locos so they will be automatically acquired on reconnection
  * **0** = Function button. Followed by...
    * the function number, Followed by \# to complete.  e.g. to set function 17 you would press '\*017\#'
    * **\#** alone, to show the list of functions.
Pressing '\*' again before the '\#' will terminate the current command (but not start a new command)
* **\#** = Pressing # alone will show the actions the numbered keys (0-9) perform, outside the menu.
       Optionally, you can configure it so that it shows the Function labels from the roster

Pressing the Encoder button while the ESP32 is in Deep Sleep will revive it.

<br/>

----

### Screens

#### WiFI/SSID Connection Screens

*Start-up - browsing for SSIDs*<br />
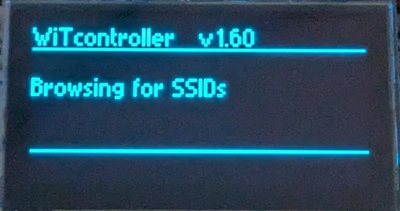
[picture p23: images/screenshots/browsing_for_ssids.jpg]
Start-up - browsing for SSIDs


*SSID (WiFi networks) list*<br />
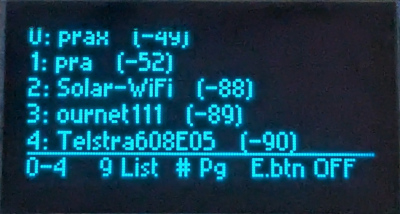
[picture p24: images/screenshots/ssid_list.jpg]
SSID list


*Trying to to connect to SSID*<br />
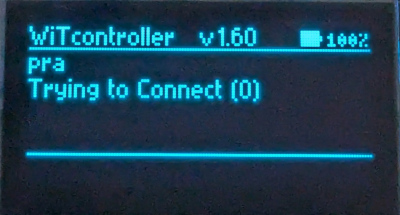
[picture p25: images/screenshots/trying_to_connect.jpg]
Trying to to connect to SSID


#### WiThrottle Server Connection Screens

*WiThrottle Server List*<br />
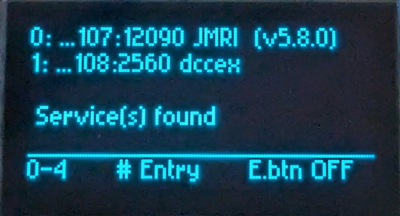
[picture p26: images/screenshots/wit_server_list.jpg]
WiThrottle Server List


#### Throttle Screen

*Throttle Screen with no loco acquired*<br />
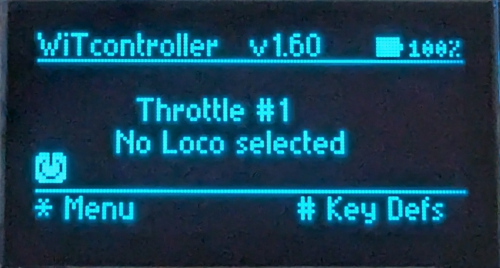
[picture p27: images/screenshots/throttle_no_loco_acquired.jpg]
Throttle Screen with no loco acquired


*Throttle Screen - with locos selected on throttle 1 and throttle 2*<br />
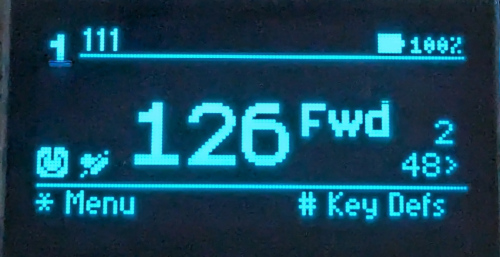
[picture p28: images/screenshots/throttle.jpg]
Throttle Screen


```
TT LLLL LLLL LLLL               BBBBB
TT ----------------------------------
f f f f f f f f f f f f f f f f f f f
              SSSSS  DDDD
              SSSSS  DDDD
G             SSSSS            
M             SSSSS              llll
P  h                          d sss d
-------------------------------------
mmmmmmmmm
```

* TT   = Current Throttle Number
* LLLL = Currently acquire loco(s) on this throttle
* SSSS = Speed of current throttle (0-126)
* DDDD = Direction of current throttle (Fwd,Rev)
* f    = State of each of the 32 functions (number displays if the function is active)<br /><br />
* llll = First Loco on *next* available throttle
* d    = Direction of next next available throttle (<,>)
* sss  = Speed of next available throttle (0-126)<br /><br />
* h    = heartbeat (only displays if heartbeat is disabled)
* M    = Speed step multiplier
* P    = Track Power
* G    = Guest Mode / Child Lock Active
* BBBB = Optional battery state
* mmmm =  menu, other instructions or broadcast messages

#### * Menu

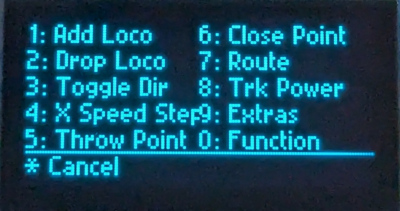
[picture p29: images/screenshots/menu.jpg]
Menu


#### # Direct Commands List

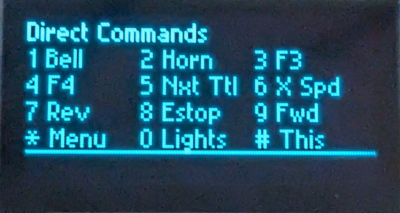
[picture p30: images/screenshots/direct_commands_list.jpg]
Direct Commands List


----

### Default number key assignments (0-9)  (outside the menu)

* 0 = FUNCTION_0 (DCC Lights)
* 1 = FUNCTION_1 (DCC Bell)
* 2 = FUNCTION_3 (DCC Horn/Whistle)
* 3 = FUNCTION_3
* 4 = FUNCTION_4
* 5 = NEXT_THROTLE
* 6 = SPEED_MULTIPLIER
* 7 = DIRECTION_REVERSE
* 8 = SPEED_STOP
* 9 = DIRECTION_FORWARD

### Allowed assignments for the 0-9 keys and/or Additional Buttons

Note: you need to edit ``config_buttons.h`` to alter these assignments   (copy ``config_buttons_example.h``)

* FUNCTION_NULL   - don't do anything
* FUNCTION_0 - FUNCTION_31
* SPEED_STOP
* SPEED_UP
* SPEED_DOWN
* SPEED_UP_FAST
* SPEED_DOWN_FAST
* SPEED_MULTIPLIER
* E_STOP   - E Stop all locos on all throttles
* E_STOP_CURRENT_LOCO - E Stop locos on current throttle only
* POWER_TOGGLE
* POWER_ON
* POWER_OFF
* SHOW_HIDE_BATTERY
* DIRECTION_TOGGLE
* DIRECTION_FORWARD
* DIRECTION_REVERSE
* NEXT_THROTTLE
* SPEED_STOP_THEN_TOGGLE_DIRECTION   - stops the loco if moving.  Toggles the direction if stationary.
* MAX_THROTTLE_INCREASE    - change the number of available throttles on-the-fly
* MAX_THROTTLE_DECREASE    - change the number of available throttles on-the-fly
* POWER_TOGGLE - track power toggle
* POWER_ON - track power on
* POWER_OFF - track power off
* THROTTLE_1   - change to a specific throttle
* THROTTLE_2   - change to a specific throttle
* THROTTLE_3   - change to a specific throttle
* THROTTLE_4   - change to a specific throttle
* THROTTLE_5   - change to a specific throttle
* THROTTLE_6   - change to a specific throttle
* SLEEP   - put device to sleep
* CUSTOM_1   - There must be already be a command defined as ``#CUSTOM_COMMAND_1 ...``
* CUSTOM_2   - There must be already be a command defined as ``#CUSTOM_COMMAND_2 ...``
* CUSTOM_3   - There must be already be a command defined as ``#CUSTOM_COMMAND_3 ...``
* CUSTOM_4   - There must be already be a command defined as ``#CUSTOM_COMMAND_4 ...``
* CUSTOM_5   - There must be already be a command defined as ``#CUSTOM_COMMAND_5 ...``
* CUSTOM_6   - There must be already be a command defined as ``#CUSTOM_COMMAND_6 ...``
* CUSTOM_7   - There must be already be a command defined as ``#CUSTOM_COMMAND_7 ...``
* CUSTOM_8   - There must be already be a command defined as ``#CUSTOM_COMMAND_8 ...``
* CUSTOM_9   - There must be already be a command defined as ``#CUSTOM_COMMAND_9 ...``
* CUSTOM_10  - There must be already be a command defined as ``#CUSTOM_COMMAND_10 ...``
* CUSTOM_10  - There must be already be a command defined as ``#CUSTOM_COMMAND_11 ...``
* HORN_OR_WHISTLE_SEARCH
* HORN_SEARCH
* WHISTLE_SEARCH
* BRAKE_SEARCH
* additional custom searches (see below)
* CUSTOM_MENU_SELECT_1   - There must be already be a command defined as ``#CUSTOM_MENU_SELECT_COMMAND_1 ...``
* CUSTOM_MENU_SELECT_2   - There must be already be a command defined as ``#CUSTOM_MENU_SELECT_COMMAND_2 ...``
* CUSTOM_MENU_SELECT_3   - There must be already be a command defined as ``#CUSTOM_MENU_SELECT_COMMAND_3 ...``
* CUSTOM_MENU_SELECT_4   - There must be already be a command defined as ``#CUSTOM_MENU_SELECT_COMMAND_4 ...``
* CUSTOM_MENU_SELECT_5   - There must be already be a command defined as ``#CUSTOM_MENU_SELECT_COMMAND_5 ...``
* CUSTOM_MENU_SELECT_6   - There must be already be a command defined as ``#CUSTOM_MENU_SELECT_COMMAND_6 ...``
* CUSTOM_MENU_SELECT_7   - There must be already be a command defined as ``#CUSTOM_MENU_SELECT_COMMAND_7 ...``
* CUSTOM_MENU_SELECT_8   - There must be already be a command defined as ``#CUSTOM_MENU_SELECT_COMMAND_8 ...``
* CUSTOM_MENU_SELECT_9   - There must be already be a command defined as ``#CUSTOM_MENU_SELECT_COMMAND_9 ...``
* CUSTOM_MENU_SELECT_10  - There must be already be a command defined as ``#CUSTOM_MENU_SELECT_COMMAND_10 ...``
* CUSTOM_MENU_SELECT_10  - There must be already be a command defined as ``#CUSTOM_MENU_SELECT_COMMAND_11 ...``

<br/>
<hr style="border: none; height: 4px; background-color: #007bff; border-radius: 2px;">

## Options and Extras

### Rotary Encoder 'sensitivity'

If you find that moving the encoder very slightly flicks the speed or the selected option back and forward, try adjusting this define by uncommenting (removing the ``//``) following line in your ``config_buttons.h`` and changing the value. (Decrease the value to make it less sensitive. Increase the value to make it more.)

``#define ENCODER_SENSITIVITY  85``

Depending on your encoder - generally try between 80 and 100 till you get expected behaviour.  The default is 85.  (Prior to version 1.109 the it was hard coded to 100.)

<hr style="height: 1px;">

### Rotary Encoder 'bounce'

If you find that moving the encoder a single click sends more than one speed command, try adjusting this define by uncommenting (removing the ``//``) following line in your ``config_buttons.h`` and changing the value. (Usually you need to increase the value.)

``#define ROTARY_ENCODER_STEPS 2``

Depending on your encoder - try 1,2,3 or 4 till you get expected behaviour.  The default is 2

<hr style="height: 1px;">

### Direction of rotation of the encoder

The default configuration is to rotate the encoder counter-clockwise to increase speed.  This made sense for the original simple case where the knob is on the top end of the case, but is not for many of the new cases that people have designed where the knob is on the front face of the case.

To change the configuration so that rotating the encoder clockwise increases speed, uncomment (remove the ``//``) following line in your ``config_buttons.h`` and change the value to true.

``#define ENCODER_ROTATION_CLOCKWISE_IS_INCREASE_SPEED                     true``

<hr style="height: 1px;">

### Direction of rotation of the encoder when the Loco is reversed

By default, when the loco is reversed, to increase the speed of the loco you need to rotate the encoder in the same direction as when the loco direction is forward.  (See the previous heading.)
If you wish to increase speed by rotating the encoder in the opposite direction when the direction is reversed you can add the following define.  Uncomment (remove the ``//``) following line in your ``config_buttons.h``.

``#define ENCODER_INVERT_ROTATION_WHEN_REVERSED                     true``

<hr style="height: 1px;">

### Optional Additional Buttons

The way to add additional buttons changed in version 1.83.  The old way will continue to work but only the new way is described here.

To use the new format:
*  ``USE_NEW_ADDITIONAL_BUTTONS_FORMAT`` must be set to ``true``
* ``NEW_MAX_ADDITIONAL_BUTTONS`` must be set to the number of buttons you want to use.  This **must** be ``1`` or more. never 0.

Then the following lists MUST have the same number of elements as NEW_MAX_ADDITIONAL_BUTTONS.

* ``NEW_ADDITIONAL_BUTTON_ACTIONS``
* ``NEW_ADDITIONAL_BUTTON_LATCHING``
* ``NEW_ADDITIONAL_BUTTON_PIN``
* ``NEW_ADDITIONAL_BUTTON_TYPE``

> [!NOTE]
>
> It is theoretically possible to add up to 11 additional buttons directly to the ESP32. <br/>
> Pins 5,15,25,26,27,32,33 are the 7 normally used for the buttons. <br/>
> However:
>
> * One of these becomes unavailable if you have an optional 4x4 keypad
> * Also one of these becomes unavailable if you use the battery test
>
> Additionally: <br/>
> Pins 34,35,36,39 can also be used, *but*:
>
> * They don't have an internal pullup, so need and external resister, and they need to configured (in config_buttons.h) as ``INPUT`` rather than ``INPUT_PULLUP`` <br/>
> * One of these pins may used by the optional 4x4 keypad <br/>
> * One of these pins may used by the optional battery monitor

For **NEW_ADDITIONAL_BUTTON_ACTIONS**

This array lists the *functions or actions* assigned to the buttons. See the list of 'Allowed assignments' above (or in [actions.h](actions.h)).

This has the general form ``NEW_ADDITIONAL_BUTTON_ACTIONS{val0, val1, .. val10, up-to-val11}``

For **NEW_ADDITIONAL_BUTTON_LATCHING**

This array lists if the functions assigned to the buttons should be *latching* or not. This is only relevant if the assigned function is for ``FUNCTION_0`` to ``FUNCTION_31``.

This has the general form ``NEW_ADDITIONAL_BUTTON_LATCHING{val0, val1, .. val10, up-to-val11}``

For **NEW_ADDITIONAL_BUTTON_PIN**

This array lists the *pins* that the buttons will be attached to.

* For pins on the ESP32 use the number shown on the board/diagram
* If you are using pins on a I2C GPIO Expansion board, they will be numbered: 0-15
* If don't want to use pin, but retain the entry set it to ``-1``.

This has the general form ``NEW_ADDITIONAL_BUTTON_PIN{val0, val1, .. val10, up-to-val11}``

For **NEW_ADDITIONAL_BUTTON_TYPE**

This array lists the type of the pin.

* Set to either INPUT_PULLUP or INPUT.  If INPUT, the pin will need an external pullup resister (e.g. 10k)
* Pins 34,35,36,39 can be used but don't have an internal pullup, so use INPUT for these

This has the general form ``NEW_ADDITIONAL_BUTTON_TYPE{val0, val1, .. val10, up-to-val11}``

See additional information in [config_button_example.h](config_buttons_example.h).

<details>

<summary>Example - Click to expand</summary>

The following example is for 5 additional buttons, one of which requires the external pullup resister.

```
#define USE_NEW_ADDITIONAL_BUTTONS_FORMAT true
#define NEW_MAX_ADDITIONAL_BUTTONS 5
#define NEW_ADDITIONAL_BUTTON_ACTIONS {\
                        E_STOP,\
                        CUSTOM_4,\
                        FUNCTION_2,\
                        FUNCTION_3,\
                        FUNCTION_4\
                        }
#define NEW_ADDITIONAL_BUTTON_LATCHING {\
                        true,\
                        true,\
                        true,\
                        true,\
                        true\
                        }
#define NEW_ADDITIONAL_BUTTON_PIN {\
                        5,\
                        15,\
                        25,\
                        26,\
                        39\
                        }
#define NEW_ADDITIONAL_BUTTON_TYPE {\
                        INPUT_PULLUP,\
                        INPUT_PULLUP,\
                        INPUT_PULLUP,\
                        INPUT_PULLUP,\
                        INPUT\
                        }
```

Which is exactly the same as...

```
#define USE_NEW_ADDITIONAL_BUTTONS_FORMAT true
#define NEW_MAX_ADDITIONAL_BUTTONS 5
#define NEW_ADDITIONAL_BUTTON_ACTIONS {E_STOP,CUSTOM_4,FUNCTION_2,FUNCTION_3,FUNCTION_4}
#define NEW_ADDITIONAL_BUTTON_LATCHING {true,true,true,true,true}
#define NEW_ADDITIONAL_BUTTON_PIN {5,15,25,26,39}
#define NEW_ADDITIONAL_BUTTON_TYPE {INPUT_PULLUP,INPUT_PULLUP,INPUT_PULLUP,INPUT_PULLUP,INPUT}
```

> *NOTE*
>
> * The ``\`` at the end of the lines is a continuation.  It means that the following line will be treated as part of the line which ends in the ``\``. <br /> i.e All the defines can just as easily be written on single lines without the ``\``s.
> * The last value in each list *must not* have a comma (,) after it.  The other values *must* have the comma (,) after.

</details>

<hr style="height: 1px;">

### Optional use of a EC11 rotary encoder (with no physical resistor pullups) in place of the KY040 encoder module

Internal GPIO pullups required if the hardware build utilises a bare EC11 rotary encoder in place of a KY040 encoder module. (The encoder module has physical pullups fitted)

``#define EC11_PULLUPS_REQUIRED         true``

If the ``EC11_PULLUPS_REQUIRED`` is set to ``false`` a KY040 module used in hardware build OR bare EC11 used but with physical pullup resistors.

If the ``EC11_PULLUPS_REQUIRED`` is set to ``true`` an EC11 used for hardware build WITHOUT any physical pullups, GPIO pullups will ne enabled in main.

The default is ``false``.

<hr style="height: 1px;">

### Optional use of different OLED displays

WitController will support any OLED display with a resolution of 128x64 that is supported by the U8g2 library.  This include displays up to 2.4 inch.

The complete list is available here: https://github.com/olikraus/u8g2/wiki/u8g2setupcpp

The ``OLED_TYPE`` define will need to be updated to whatever display you have

 This is one of the common .9 inch OLED displays (and also for a common 2.4 inch) and is included by default

``#define OLED_TYPE U8G2_SSD1306_128X64_NONAME_F_HW_I2C u8g2(U8G2_R0, /* reset=*/ U8X8_PIN_NONE, /* clock=*/ 22, /* data=*/ 23);``

This is one of the common 1.3 inch OLED displays

``#define OLED_TYPE U8G2_SH1106_128X64_NONAME_F_HW_I2C u8g2(U8G2_R0, /* reset=*/ U8X8_PIN_NONE, /* clock=*/ 22, /* data=*/ 23);``

This one works with a 2.42 inch SSD1309 based oLED

``#define OLED_TYPE U8G2_SSD1309_128X64_NONAME2_F_HW_I2C u8g2(U8G2_R0, /* reset=*/ U8X8_PIN_NONE, /* clock=*/ 22, /* data=*/ 23);``

See [config_buttons_example.h](config_buttons_example.h) for more information.

<hr style="height: 1px;">

### Optional use of a potentiometer (pot) instead of the encoder for the throttle

``config_buttons.h`` can include the following optional defines:

* ``#define USE_ROTARY_ENCODER_FOR_THROTTLE false``
* ``#define THROTTLE_POT_PIN 39``
* ``#define THROTTLE_POT_USE_NOTCHES true``
* ``#define THROTTLE_POT_NOTCH_VALUES {1,585,1170,1755,2340,2925,3510,4094}``
* ``#define THROTTLE_POT_NOTCH_SPEEDS {0,18,36,54,72,90,108,127}``

If ``USE_ROTARY_ENCODER_FOR_THROTTLE`` is set to ``false`` the rotary encoder is ignored for thottle/speed control and a pot on the pin defined with ``THROTTLE_POT_PIN`` will be used instead.

You must specify the PIN to be used.  Currently PINs 34, 35 and 39 are the only ones that cannot be used by the app for other purposes, so these are the safest to use.  This should be connected to the centre pin of the pot. The 3v and GND should be connected to the outer pins of the pot.

The pot can be set to have 8 defined 'notches' (the default) or just a linear value.

If you want to have the 8 notches:

a) You must define the values the pot will send at each of 8 points - ``THROTTLE_POT_NOTCH_VALUES``.  Note that you should avoid the value zero (0) for notch zero.  Use at least 1 instead.

  The example values above are useble for a 10k ohm pot but any value pot can be used. Just adjust the numbers.

b) You must define what speed should be sent for each notch - ``THROTTLE_POT_NOTCH_SPEEDS``

If you want a linear speed instead of notches:

a) You must define the values the pot will send at at zero throw and full throw in the first and last of the 8 values in ``THROTTLE_POT_NOTCH_VALUES``.  The other values will be ignored but you still need to include 8 values.  (They can be zero.)  Note that you should avoid the value zero (0) for notch zero.  Use at least 1 instead.

Sumner Patterson has developed an app to help find the appropriate pot values for the ``THROTTLE_POT_NOTCH_VALUES``.

<hr style="height: 1px;">

### Optional use of a voltage divider to show the battery charge level

See diagram above for how to wire in the volage divider.  47k resistors are used, but this can be varied as long as the output to the pin is limited to below 3.3v. See additional information related to the Pangodream Library that WiTcontroller uses here... https://www.pangodream.es/tag/18650-ion-li

The diagram has the voltage divider spliced into battery leads, but you can solder the positive in to the back of the battery connector (on the ESP32) if you prefer. The ground can be taken from any ground pin.

*To enable the battery monitor*, set the following to ``true``. The default is ``false``.

``#define USE_BATTERY_TEST true``

*To set which pin to use.* The default is ``34``.  In theory 34, 35, 36, or 39 should be able to be used, but only 34 and 36 have been tested.   (36 is marked 'VP' on the board.  39 is marked 'VN' on the board.)

``#define BATTERY_TEST_PIN 34``

If the battery does not show 100% when plugged into the charger, you may need to adjust this value. The default is ``1.7``.

``#define BATTERY_CONVERSION_FACTOR 1.7``

  To help work out the correct BATTERY_CONVERSION_FACTOR, you can enable some serial monitor messages that will assist.

  In your ``config_buttons.h`` add (or uncomment -remove the ``//``) this define:
  
  ``#define WITCONTROLLER_DEBUG    0``

  a) **Make sure your battery is fully charged** first! <br/>
  b) Upload the code WiTcontroller code if you have not already done so.  <br/>
  c) Open the serial monitor.  <br/>
  d) Wait. (Don't connect to a WiThrottle server.) <br/>
  You will see lines like...

  ```
  BATTERY TestValue: 100 (10003)
  BATTERY lastAnalogReadValue: 2491 (10003)
  BATTERY If Battery full, BATTERY_CONVERSION_FACTOR should be: 1.69 (10014)
  ```

  Let it run for a while. <br/>
  e) Note one of the recommended values (it will vary a bit) and enter it into the define in your ``config_buttons.h`` <br/>
  f) Re-upload code and connect to a server <br/>
  g) Confirm that the battery reads 100% (repeat if not) <br/>
  h) Run the WiTcontroller on battery for few hours and confirm the battery level is droping at an expected rate.  <br/>
      (adjust the conversion factor if not.)

*To show the calculated percentage*, set the following to ``true`` The default is ``false``.

``#define USE_BATTERY_PERCENT_AS_WELL_AS_ICON true``

*To force the WiThrottle to go to sleep at a specific level*, set this value. (e.g. to 3 or 5.) A value of less than zero (e.g. -1) will disable the feature. By default it is disabled (-1).

``#define USE_BATTERY_SLEEP_AT_PERCENT 3``

The display of the battery can be temporarily toggled by setting a key or button to ``SHOW_HIDE_BATTERY``.  The display will cycle between none, icon only and icon plus percent value. Note that ``USE_BATTERY_TEST`` must be set to `true` for this to have any effect. By default it is disabled (0).

> [!NOTE]
>
> I recommend adding a physical power switch to disconnect the battery as this feature will, slowly, continually drain the battery, even when not being used.

<hr style="height: 1px;">

### YaMoRC Command Stations / Heartbeat Period

``#define DEFAULT_HEARTBEAT_PERIOD 10``

The heartbeat period defaults to 10 seconds.  The server should send the period that it is expecting on connection and overide the default, so generally you should never need to adjust this.

It is believed that the YaMoRC Command Stations are not sending this as the should (according to the WiThrottle specification).  For those, and any other WiThrottle that do not send it, uncomment or add the define above and adjust the number of seconds to match the setting on the server.

<hr style="height: 1px;">

### Optional Startup Commands

``#define STARTUP_COMMAND_1 ""`` .. ``#define STARTUP_COMMAND_4 ""``

Optional. If defined, up to four commands will be executed, in order, after connection to the WiThrottle Server.
Each must be ***ONLY ONE*** single valid command.  Either a direct action or a menu action.  Any can be blank or not defined, the others will still be executed.

> [!NOTE]
>
> Selecting from the roster, routes, turnouts/points, etc. is not possible as the commands will execute before the roster, routes,  turnouts/points load.

<hr style="height: 1px;">

### Optionally automatically acquire the only loco in the roster

``#define ACQUIRE_ROSTER_ENTRY_IF_ONLY_ONE true``

Enabling this option will automatically acquire the only roster entry after connection to the WiThrottle Server, but only if there is ***only one*** roster entry.

<hr style="height: 1px;">

### Optional Guest Mode

Modified from code by *Will Jayne - Coventry Railworks*

Guest mode allows you to lock the keyboard by pressing and holding two *additional buttons* together for 1 second (default).  Any *additional buttons* can be configured to activate/deactivate this.  The feature is not enabled by default.

Guest Mode shows a lock indicator on screen and can optionally illuminate a LED indicator. It disables any kepad inputs as well as the "next throttle" function.

*I added this primarily so that children can use the throttle and quick function buttons, without accidentally entering any menu.
Will*

The feature is not enabled by default.  The featue can only be activted from the Throttle Speed screen. (i.e. not in a menu.)

``#define GUEST_MODE_ENABLED true``

Pins for the 'Additional Buttons' that need to be pressed to activate/deactivate the feature.
Defaults to 5 and 15, which are the first two default additional button pins.
***These must correspond to two of the 'additional buttons' pins.  (See above)***

``#define GUEST_MODE_PIN_1 5``
``#define GUEST_MODE_PIN_2 5``

Optional LED indicator PIN number. Defaults to disabled (-1)

``#define GUEST_MODE_LED_PIN 2``

Timing parameters

``#define GUEST_MODE_HOLD_DURATION 1000``
``#define GESTURE_PARTNER_WINDOW 250``

Optionally allow access to the direct keypad commands. .i.e. everything except '*'. Defaults to false.

``#define GUEST_MODE_ALLOW_DIRECT_KEYBOARD_COMMANDS true``

Optionally allow access to the other throttles (NEXT_THROTTLE). Defaults to false.

``#define GUEST_MODE_ALLOW_NEXT_THROTTLE true``

Note: Holding the guest mode activation mode buttons can currently be problematic if you have assigned custom menu commands (see below) to those buttons.  I am working on a solution for that.

<hr style="height: 1px;">

### Optional Search Function commands

Modified from code by *Will Jayne - Coventry Railworks*

From version 1.113, some additional asignable commands are available: ``HORN_OR_WHISTLE_SEARCH``, ``HORN_SEARCH``, ``WHISTLE_SEARCH``  and ``BRAKE_SEACH``

If one of these are assigned to an 'Additional Button', when it is pressed, it will search for the term ("Horn" or "Whistle", "Horn", "Whistle" or "Brake") in the available functions in the current loco, and activate/deacivate the first function it finds that *contains* that term.  Optionally, it will activate any one of the functions that conatin the term randomly.

You can change the terms they search for by adding (or uncommenting) a define in ``config_buttons.h`` , e.g. to the search for "Siren" instead of "Horn" use (case insensitive):

``#define FUNCTION_SEARCH_LABELS { {"Siren","Whistle"}, {"Siren",""}, {"Whistle",""}, {"Brake",""}, {"Bell",""} }``

Note: Each search term is a either/or pair. e.g. ``{"Horn","Whistle"}`` Either of the two term eill be concidered a match. If you only want to one work, leave the second word as an empty string. e.g. ``{"Horn",""}``

You can also add additional search term by redefining all the required terms

e.g. To add "Bell" and "Mute" searches you would add all the lines below:

```c++
#define BELL_SEARCH 900 // abitrary name. number must be 900 or greater and be unique
#define MUTE_SEARCH 901 // abitrary name. number must be 900 or greater and be unique
#define MAX_FUNCTION_SEARCH 6
#define FUNCTION_SEARCH_LABELS { {"Horn","Whistle"}, {"Horn",""}, {"Whistle",""}, {"Brake",""}, {"Bell",""}, {"Mute",""} }
#define FUNCTION_SEARCH_IDS {HORN_OR_WHISTLE_SEARCH, HORN_SEARCH, WHISTLE_SEARCH, BRAKE_SEARCH, BELL_SEARCH, MUTE_SEARCH}
```

Then assign an 'additional button' to ``BELL SEARCH`` or ``MUTE_SEARCH``.

Note: The name of each ``???_SEARCH`` can be anything, but must be unique. The assigned number must 900 or greater, and must be unique.

By default only the first matching function will be activated. You can instead have one random of the matching functions be activated by enabling (uncommenting) the following define:

``#define FUNCTION_SEARCH_RANDOM_MATCH true``

<hr style="height: 1px;">

### Additional/Optional User Defined Commands

Up to 11 custom Withrotle commands can be assigned to the additional buttons.

These can be any legitimate WiThrottle protocol command enclosed in quotes or double quotes. refer to https://www.jmri.org/help/en/package/jmri/jmrit/withrottle/Protocol.shtml

These are created by assing values to ``CUSTOM_COMMAND_1`` to ``CUSTOM_COMMAND_11``. e.g.

```c++
#define CUSTOM_COMMAND_1 "HMHello World" // alert message
#define CUSTOM_COMMAND_2 "PRA2R500" // set route R500  (DCCEX system route prefix is 'R')
```

To use these custom WiThrottle commands on additional buttons you assign the button the value ``CUSTOM_1`` to ``CUSTOM_11``.  (See the example above.)

Note: The definition of the command and what you assign to the additional button are different.

<hr style="height: 1px;">

### Additional / optional Custom Menu Select Commands

Up to 11 custom menu commands can be assigned to the additional buttons.

These can be any legitimate menu character sequence.  Each can can contain multiple commands.

These are created by assing values to ``CUSTOM_MENU_SELECT_COMMAND_1`` to ``CUSTOM_MENU_SELECT_COMMAND_1``. e.g.

```c++
#define CUSTOM_MENU_SELECT_COMMAND_1 "*1" // Open the add loco menu screen
#define CUSTOM_MENU_SELECT_COMMAND_2 "*1999#" // Select loco 999 and return to the throttle screen
#define CUSTOM_MENU_SELECT_COMMAND_3 "*2#*1888#*1999#" // Drop the current locos, then select locos 888 and 999 and return to the throttle screen
```

To use these custom menu commands on additional buttons you assign the button the value ``CUSTOM_MENU_SELECT_1`` to ``CUSTOM_MENU_SELECT_11``.  (See the example above.)

Note: The definition of the command and what you assign to the additional button are different.
Note: Custom menu commands are fully disabled in guest mode.

<hr style="height: 1px;">

### WiFi Scanning options

``#define USE_FAST_WIFI_SCAN_METHOD true``

To do a Fast Scan for SSIDs, uncomment or add the line above in your ``config_network.h``.  Fast scans are not as through. By default this option is disabled.

``#define SORT_WIFI_NETWORKS true``

The 'found' SSIDs will not be sorted by default (from version v1.98). To restore this feature, uncomment or add the line above in your ``config_network.h``.  If enabled, the SSIDs are sorted by signal strength. By default this option is disabled.

> [!NOTE]
>
> Sorting can't be used if the Fast Scan is enabled.

``#define BYPASS_WIFI_SCAN_ON_STARTUP true``

This option to allows you to bypass the initial WiFi scan.  The WiTcontroller will instead show you the list of SSIDs you have defined in ``config_network.h``.  From that you can still to the scan if you wish by pressing ``#``.  By default this option is disabled and the network will be scanned at startup.

> [!NOTE]
>
> Some ESP32s seem to have an intermitient WiFi problem that causes the WifI Scan to lockup the device.  This option may be may be useful in this situation.

<hr style="height: 1px;">

### Languages and localisation

#### Instructions for German Translations - Anleitung für deutsche Übersetzungen

The file [language_deutsch.h](language_deutsch.h) contains German translations (by Bastian Zechendorf).  Uncomment (or add) the ``#include "language_deutsch.h"`` line in ``config_buttons.h`` to see menus and messages in German.

You can override any of these translations individually by adding an appropriate ``#define`` statement in the ``config_buttons.h``, but it *must* be *before* the ``#include...`` statement.

Die Datei ``language_deutsch.h`` enthält deutsche Übersetzungen (von Bastian Zechendorf).  Kommentieren Sie die Zeile ``#include "language_deutsch.h"`` in ``config_buttons.h`` aus (oder fügen Sie sie hinzu), um Menüs und Meldungen auf Deutsch anzuzeigen.

Sie können jede dieser Übersetzungen einzeln überschreiben, indem Sie eine entsprechende ``#define`` -Anweisung in ``config_buttons.h`` hinzufügen, diese muss jedoch *vor* der ``#include...`` -anweisung stehen.

Ich würde mich über jede Hilfe zur Verbesserung dieser Übersetzungen freuen.
Bei Interesse kontaktieren Sie mich bitte direkt für eine Anleitung.

<hr style="height: 1px;">

#### Instructions for Italian Translations - Istruzioni per la traduzione in Italiano

Il file [language_italiano.h](language_italiano.h) contiene la traduzione italiana (by Roberto B). Rimuovere il commento o aggiungere la linea ``#include language_italiano.h`` nel file ``config_buttons.h`` per avere menù e messaggi in Italiano.

Si può sovrascrivere una qualunque di queste traduzioni individualmente aggiungendo la relativa ``#define`` nel file ``config_buttons.h`` ma deve essere fatto assolutamente prima dell' ``#include...`` della traduzione.

Qualunque contributo è gradito.
Per ogni questione, il contatto ufficiale è il canale Discord di DCC-EX nella sezione wifi-throttles.

<hr style="height: 1px;">

#### Instructions for Dutch Translations - Instructies voor de Nederlandse vertalingen

Het bestand [language_nederlands.h](language_nederlands.h) bevat de Nederlandse vertalingen (door Hans Metselaar). Verwijder het commentaar voor de regel ``#include "language_nederlands.h"`` (of voeg deze toe) in ``config_buttons.h`` om de menu’s en meldingen in het Nederlands weer te geven.

Je kunt ieder van deze vertalingen individueel overschrijven door het desbetreffende ``#define`` statement in de ``config_buttons.h`` toe te voegen, deze *moet* dan voor het ``#include...`` statement worden geplaatst.

<hr style="height: 1px;">

#### Instructions for Chinese Translations - 中文翻译说明

The file [language_chinese.h] contains Chinese translations (by Lin Huiyu).  

To see menus and messages in Chinese:

* Uncomment (or add) the ``#include "language_chinese.h"`` line in ``config_buttons.h``.
* Uncomment (or add) the ``#define FONT_DEFAULT u8g2_font_boutique_bitmap_7x7_t_gb2312`` line in ``config_buttons.h``.
* Uncomment (or add) the ``#define FONT_DIRECTION u8g2_font_wqy13_t_gb2312a`` line in ``config_buttons.h``.

You can override any of these translations individually by adding an appropriate ``#define`` statement in the ``config_buttons.h``, but it *must* be *before* the ``#include...`` statement.

文件 [language_chinese.h] 包含的中文翻译内容，由林辉玉完成。

如需显示中文菜单与信息，请按以下步骤操作：

* 在 ``config_buttons.h`` 文件中，取消注释（或添加）此行：``#include "language_chinese.h"``。
* 在 ``config_buttons.h`` 文件中，取消注释（或添加）此行：``#define FONT_DEFAULT u8g2_font_boutique_bitmap_7x7_t_gb2312``。
* 在 ``config_buttons.h`` 文件中，取消注释（或添加）此行：``#define FONT_DIRECTION u8g2_font_wqy13_t_gb2312a``。

您可以在 ``config_buttons.h`` 文件中通过添加相应的 ``#define`` 预编译宏定义来个别覆盖这些翻译，但该定义必须出现于 ``#include...`` 语句之前。

<hr style="height: 1px;">

#### Instructions for Other Translations

If you create a copy of the file ``language_deutsch.h`` (with a new name) and change the German text it contains to any language you wish (using the English text on the right as a guide to what is needed) you can add that file as an include in ``config_buttons.h``.

I would welcome it if you then sent me the file you created for inclusion in this repository.

I would appreciate any assistance to improve or add to the translations.
If you are interested, please contact me directly for instructions.

<br/>

<hr style="border: none; height: 4px; background-color: #007bff; border-radius: 2px;">

## Modifying the code

If you plan to modify the code to make you own version, it is recommended that you create your own GitHub fork of my repository and post your mods there.

[Instructions on how to do so are here](forking.md).

<hr style="border: none; height: 4px; background-color: #007bff; border-radius: 2px;">

## Change Log

[See full change log/ version history](change_log.md)

<hr style="border: none; height: 4px; background-color: #007bff; border-radius: 2px;">

## Contact Me

I can be contacted by:

a) Via email  ``akersp62 @ gmail.com``   *(remove the spaces)*

b) On the 'wifi-throttle' Channel on the **DCC-EX Discord** server https://discord.gg/8ghsjsBup8.  My handle is ``flash62au (Peter A)``

c) By creating an 'Issue' here on GitHub.  (Not recommended, but I will respond.)

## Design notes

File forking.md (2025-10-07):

# Instructions for Forking the code

If you plan to modify the code it is recommended that you create your own GitHub fork of my repository and post your mods there.

That way:

* It is easier to accept any changes I make in my origin repository. </br> Git will generally merge the changes automatically. (Rather you than manually patching each each time.)
* You can, if you wish, send your changes to me, via Pull Requests from your fork, for inclusion in the origin
* It is easier for other people to pull down your version, and any subsequent changes to your version, to try it out without effecting their other versions. 

## Required Software

* [GitHub Desktop](https://desktop.github.com/download/) (or similar)
* [Arduino IDE](https://www.arduino.cc/en/software/) or [Visual Studio Code (VSC)](https://code.visualstudio.com/download)

> [!NOTE]
> **Visual Studio Code** is far superior to the **Ardunio IDE** for this type of coding.

## Procedure

### Procedure Overview

Ideally the cycle would look like this..

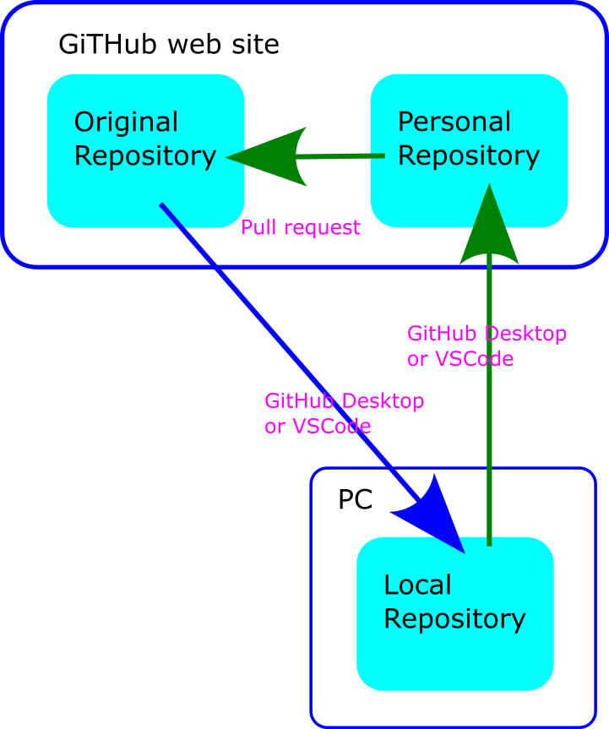
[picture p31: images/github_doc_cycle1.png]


Changes to the original would be pulled down from the origin repository directly to your local (PC) repository.  You would push your changes to your GitHub website repository. Then create a *Pull request* to send them to the origin for review.

While this is possible, both **GitHub Desktop** and **VSCode** make it extremely cumbersome to do so.

*So instead a slightly longer approach is described below...*

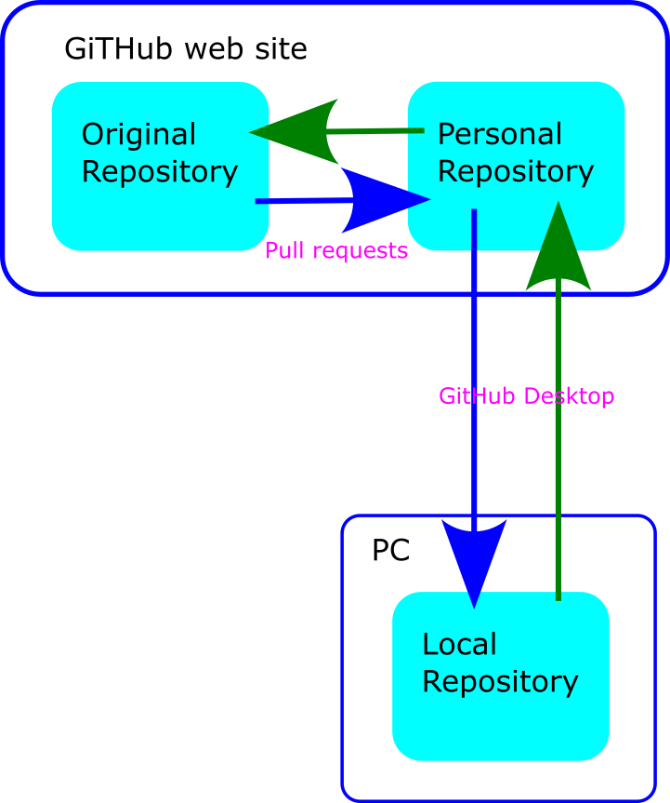
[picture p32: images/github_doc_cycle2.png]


Changes to the original would be pulled down from the origin repository to your GitHub website repository with a *Pull Request*.  You will then pull those changes to you local (PC) repository. You will push your changes to your GitHub website repository. Then create a *Pull Request* to send them to the origin for review.

There are a number of possible ways to do this but the instructions below are reasonably simple and work:

One time only:

1. Cloning the repository on the **GitHub website**
2. Using **GitHub Desktop** to download the repository to your PC

Ongoing:

3. Opening the repository in the **Arduino IDE** or **VSCode**
4. Making your changes
5. Preview/run your changes on your PC
6. Using **GitHub Desktop** to *push* your changes back to your clone of the Repository on GitHub
7. Creating a *pull request* to send your changes for review

You will periodically need to update your repository:

1. Create a pull request on the **GitHub website** to get any changes from the original repository to your repository on GitHub website
2. Use **GitHub Desktop** to pull the changes to your repository on your PC

One time only
----

#### 1. Cloning the repository on GitHub website

1. First you will need to create an account on Github if you don't already have one.
2. Go to the origin repository ``https://github.com/flash62au/WiTcontroller``
3. Click on the `Fork` button and create a new fork.

You will now have a new fork located at ``https://github.com/<your_account_name>/WiTcontroller`` (or whatever you called it).  Take note of this for the next step.

#### 2. Download the repository to your PC with GitHib Desktop

In **GitHub Desktop**:

1. Select `File` --> `Clone Repository`
2. Enter the name of you repository ``<your_account_name>/WiTcontroller`` (or whatever you called it).
3. Select a location on your PC to store the repository.
4. Click `Clone`

A copy of the repository should now be on the PC.

If you are using VSCode, you can open it in VSCode by selecting ``Repository -> Open in Visual Studio Code``

Ongoing
-------

#### 3. Open the repository in VSCode

You can open the repository in the Arduino IDE or VSCode at any time by using `File` --> `Open Folder` and navigating to the folder you selected in step 2.

You can subsequently open the repository in VSCode using `File` --> `Open Recent` and selecting the repository name.

You can subsequently open the repository in VSCode from **GitHub Desktop**.

### 4. Make your changes

You can use the navigation tree on the left to find the file you want to change. Clicking on a file will open it in the edit window.

Test your changes!

### 5. Push your changes to your GitHub repository

You will need to

* Commit your changes
* Push your changes

In **GitHub Desktop**:

* Open/select the repository
* note and review the changes that have been made
* Add a ``Summary`` of your changes
* Add a ``Description`` of your changes, if the summary is not sufficient space
* click `Commit to Main`
* click `Push origin`

### 6. Creating a *pull request* to send your changes for review

1. Open the **GitHub website**
2. Open/select your repository ``https://github.com/<your_account_name>/WiTcontroller`` (or whatever you called it)

On the 'code' page you should see "This branch is *x* commit(s) ahead of DCC-EX/dcc-ex.github.io:sphinx."

3. Click on the `x commit(s) ahead of` hyperlink
5. Confirm or add to the `title` and `documentation` fields
6. Click on the `Create pull request` button

This creates a Pull Pequest to be reviewed by the developer (flash62au).

Periodic
---------

To see the changes that other people have made to the origin repository you need to periodically refresh your repository on both GitHub website and locally 

#### a. Get any changes to your repository on GitHub website

1. Open the **GitHub website**
2. open/select your repository ``https://github.com/<your_account_name>/WiTcontroller`` (or whatever you called it)

On the 'code' page you should see "This branch is *x* commit(s) behind flash62au/WiTcontroller."

If does not say you are 'behind' there is nothing to do.  Stop here.

If you are behind...

3. Click on the `x commit(s) behind` hyperlink
4. Click on the `Create pull request` button
5. Add to the title and/or documentation fields.  This does not matter so entering just ``Catchup`` is fine.
6. Click on the `Merge pull request` button
7. Click on the `Confirm merge` button

Any changes are now also in your repository on the GitHub website.

### b. Pull the changes to your repository on your PC

In **GitHub Desktop**:

1. Click on the `Fetch origin` button`

Any changes are now also in your repository on your PC.

----

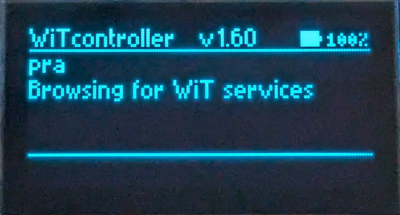
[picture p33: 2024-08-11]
images/screenshots/browsing_for_wit_services.jpg

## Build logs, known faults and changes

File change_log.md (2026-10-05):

# Change Log

## Versions

### V1.120

- New option HIDE_FUNCTION_NUMBERS_WITH_LABELS

### V1.119

- New option SHOW_LONGER_FUNCTION_LABELS

### V1.118

- New option USE_LARGER_FONT_FOR_LOCOS
- Bug fix. Don't clear the function states when selecting a subsequent loco of a consist
- Ignore entered DCC addresses greater than 10239 or equal to 0

### V1.117

- New, experimental, configuration button generation page
- New, experimental, configuration network generation page
- New option SPEED_ZERO_ON_DIRECTION_CHANGE from Nico/ocin
- New option DEFAULT_SPEED_STEP_MULTIPLIER from Nico/ocin

### V1.116

- Disable all custom menu commands if guest mode is active.

### V1.115

- Added option to allow the use of the keypad direct commands in guest mode. It is disabled by default.
- Added separate option for allowing NEXT_THROTTLE in guest mode. It is disabled by default.

### V1.114

- Added the optional custom menu commands

### V1.113

- Added Guest Mode - modified from the code from Will Jayne - Coventry Railworks
- Added Function Search - modified from the code from Will Jayne - Coventry Railworks
- Moved contents on config_keyboard_etc.h to static.h

### V1.112

- Increase the number of supported custom commands to 11

### V1.111

- bug fix for 1.110

### V1.110

- Now 'guesses' that there will be a server on 192.168.4.1:2650 if the SSID name contains "DCCEX" or "DCC-EX"

### V1.109

- Added ``#define ENCODER_SENSITIVITY``  Default is now 85 for the encoder acceleration instead of the previously fixed 100, but can be overridden
- Added feature to automatically store all entered passwords in non-volatile memory.

### V1.108

- When trying to connect to a DCC-EX EX-CommandStation it will now try the 'guessed' password on the first attempt.  Then, if it fails to connect, it will ask for the password on the second attempt.

### V1.107

- Dutch translations by Hans Metselaar

### V1.106

- bug fix for the user defined menus

### V1.105

- Initial Chinese language support.  Needed a new define to be able to override the direction font

### V1.104

- Option to invert the meaning of the encoder rotation when the loco is reversed ``#define ENCODER_INVERT_ROTATION_WHEN_REVERSED true``

### V1.103

- Option to bypass the initial WiFi scan ``#define BYPASS_WIFI_SCAN_ON_STARTUP true``

### V1.102

- Included a 15 second timeout for the new SSID scan

### V1.101

- If the SSID scan fails, it lets you choose from the list in the config_network.h 

### V1.100

- Changed the SSID scan to a non-blocking approach 

### V1.99

- removed some of the code added in the previous version as it was not proving to be helpful.

### V1.98

- The SSID scan will no longer sort by default
- Addition of two defines for the SSID scan ``SORT_WIFI_NETWORKS`` and ``USE_FAST_WIFI_SCAN_METHOD``
  - Use ``#define SORT_WIFI_NETWORKS true`` to sort the SSIDs
  - Use ``#define USE_FAST_WIFI_SCAN_METHOD true`` to use a faster scanning method
- Now disconects the WiFi as a precaution on startup
- Fixed a bug with use of the WiFi country codes
- Realised that ``#define ENFORCED_COUNTRY_CODE true`` is not actually used by the code.  I will look into that later

### V1.97

- Additional logging

### V1.96

- Changed the default for ``USE_BATTERY_SLEEP_AT_PERCENT`` to ``#define USE_BATTERY_SLEEP_AT_PERCENT 0``.  This turns the automatic sleep on low battery off by default.

### V1.95

- Added MDNS_WAIT_TIME define

### V1.94

- EStop bug fix from https://github.com/markwtech

### V1.93

- Added define for DEFAULT_HEARTBEAT_PERIOD. Defaults to 10 seconds.  Only needed if the server does not send the period as it should.

### V1.92

- Additional button option SLEEP.  Will put the ESP32 to sleep. (i.e. turn off)

### V1.91

- Optional use of the WiFi Country Code. See ``config_network_example.h`` for more information

### V1.90

- Option to release locos in consist/mu by the index rather than the Address. New optional ``#define CONSIST_RELEASE_BY_INDEX true``

### V1.89

- Bug fix for SPEED_STOP SPEED_UP SPEED_DOWN SPEED_UP_FAST SPEED_DOWN_FAST E_STOP SPEED_MULTIPLIER

### V1.88

- Additional actions to change to specific throttle  THROTTLE_1 THROTTLE_2 THROTTLE_3 THROTTLE_4 THROTTLE_5 THROTTLE_6

### V1.87

- support UTF8 fonts better
- Italian Translations by Roberto B
- able to override the default font (not recommended)
- add define for ``CUSTOM_APPNAME``

### V1.86

- added missing debug messages for the battery

### V1.85

- bug fix for when using the Arduino IDE

### V1.84

- New set of defines to allow for an indefinite number of additional buttons. This requires the use of new set of defines that override the old style ones. <br/> At the moment you can only have up to 11 buttons.
- Bug fix for momentary functions selected from the roster

### V1.83

- log any unknown commands from the server.  Requires WiThrottleProtocol version 1.1.26 or later

### V1.82

- Made ``RESTORE_ACQUIRED_LOCOS`` default to true.
  - Added an Extra Menu option to save the current locos
  - Removed the save when deliberately disconnected or slept the device (extra menu ``#96`` or ``#97``)

### V1.81

- Show the battery status on the Start, SSID browse, Wit browse and Shutdown screens.

### V1.80

- Added ``RESTORE_ACQUIRED_LOCOS`` option. If this option is enabled, and you have deliberately disconnected or slept the device (extra menu ``#96`` or ``#97``), then the next time you connect the device it will try to load the previously acquired locos.

### V1.78

- Added ``DROP_BEFORE_ACQUIRE`` option and also toggle for this in the Extras menu

### V1.77

- Bug fix for when a DCC-EX EX-CommandStation has the password changed from the default.

### V1.77

- The additional CR+LF are now sent ahead of all commands to all command stations by default. This was originally only sent for WiFiTrax, but other commercial CSs seem to have the same issue that this resolved. This can be disabled if needed with ``#define SEND_LEADING_CR_LF_FOR_COMMANDS false`` in ``confing_network.h``.
- Added a message when the server has just connected and is caught up receiving the roster etc. and is unable to process commands yet.

### V1.76

- Option to automatically acquire the only roster entry on connection to the WiThrottle server, but only if there is ***only one*** roster entry.  ``#define ACQUIRE_ROSTER_ENTRY_IF_ONLY_ONE true``

### V1.75

- Option for up to four start-up commands ``#define STARTUP_COMMAND_1 ""`` .. ``#define STARTUP_COMMAND_4 ""``

### V1.74

- German translations by Bastian Zechendorf.
- Made it simpler to change the language.
- Improvements for non-English language display.
- Bug fix. Removed duplicated first entry in the Roster (at the end).

### V1.73

- Add debug level option ``#define DEBUG_LEVEL``
- A bug in the heartbeat send in the protocol library was fixed at the same time as this release.
- if heartbeat is enabled, deliberately send the command to server to start it. (I had previously assumed that this was not required.)

### V1.72

- add the ability to sort the roster with the new define ``ROSTER_SORT_SEQUENCE``
   - 0 = no sorting.  As it comes from the server
   - 1 = sort by name (first 10 chars only)  - Default
   - 2 = sort by DCC Address

### V1.71

- add the ability to define the consist follow function options for all 32 functions ``CONSIST_FUNCTION_FOLLOW_F0`` to ``CONSIST_FUNCTION_FOLLOW_F31``

### V1.70

- add define to enable or disable the heartbeat by default    ``#define HEARTBEAT_ENABLED true``

### V1.69

- New define added for if no response is received from the server in the specified period (milliseconds), shut down. MAX_HEARTBEAT_PERIOD   default is 4 minutes = 240000 

### V1.68

- improve bouncing on the pot values
- bug fix for functions list & menus closing when the pot value bounces

### V1.67

- bug fix for adding locos greater than 300 and less than 499

### V1.66

- Add support for setting the additional button as latching or non-latching, overriding the WiThrottle defaults. Requires WiThrottleProtocol version 1.1.24.

### V1.65

- Fix for individual loco direction (facing) changes in a consist. Requires WiThrottleProtocol version 1.1.23 or later

### V1.63 - v1.64

- bug fix for the user defined menus

### V1.62

- rewrite of the menu code to support user defined menus
- bug fix for the Edit Consist not working

### V1.61

- Bug fix - Speed step multiplier not being displayed
- Added screenshots to the Readme

### V1.60

- ignore broadcast alert "Steal from other WiThrottle or JMRI throttle Required"

### V1.59

- Experimental attempt to automatically steal locos on Dijitrax systems

### V1.58

- bug fix when not using the battery test

### V1.56 / 1.57

- Moved the battery position to the top line
- added an Action to show or hide the battery
- Added some of the UI improvements from HandCab
- Fixed the E_STOP VS E_STOP_CURRENT_LOCO. Requires WiThrottleProtocol version 1.1.20 to actually work differently.
- Updated documentation. (Particularly on the use of the battery)

### V1.55

- automated fix the latest versions of the ESP32 Board Library (3.0.0 and later) having renamed an attribute. The code now automatically adjusts for this.  
- German translation file included

### V1.54

- minor format change 

### V1.53

- Add support for hardware build that utilises a bare EC11 rotary encoder (with no physical resistor pullups) in place of the KY040 encoder module (which incorporates physical pullups)
- This version will switch on GPIO internal pullups if EC11_PULLUPS_REQUIRED is set true in config_buttons.h
- added auto deep sleep on low battery 

### V1.52

- Made two changes in main code 1. Comment out random values when displaying battery percentage
- and 2.Invert logic for the test to display the battery percentage 

### V1.51

- changed option to have the battery to show icon as well as a percent

### V1.50

- option to have the battery to show as a percent

### V1.49

- change the battery check to once ever 10 seconds

### V1.48

- change the battery charge level to an icon/glyph

### V1.47

- support for optionally using a voltage divider to show the battery charge level

### V1.46

- support for optionally using a potentiometer (pot) instead of the encoder for the throttle

### V1.45

- support for 4x4 keypads

### V1.44

- support for optional custom commands

### V1.43

- bug fix

### V1.43

 - text, button and display PIN configurations moved to defines that can be overridden in personal config_buttons_etc.h files
 - no functional changes

### V1.42

 - minor bug fix
 
### V1.41

  - support for broadcast messages. Requires WiThrottleProtocol version 1.1.12 or later.

### V1.40

 - fix for the debounce of the rotary encoder button. Will now ignore rotations when the button is pressed for (default) 200ms.  The #define for the debounce has been moved from config_keypad_etc.h to config_buttons as: #define ROTARY_ENCODER_DEBOUNCE_TIME 200

### V1.38 & V1.39 

- fix problem with wifiTrax

### V1.36 & V1.37

- failed attempt to fix problem with wifiTrax

### V1.35

- add option to send commands twice

### V1.34

- minimum time separation/delay between commands sent

### V1.33

- changes to allow the use of VSC

### V1.32

- add support for 32 functions
- bypass WiT server search if EX-CS is in AP mode

### v1.31

- option to auto-connect to first SSID

### prior 

- various

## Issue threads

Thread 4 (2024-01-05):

Disconnects and resets the DCC EX station

2wheelsnz, 2024-01-05:
I have just built this controller and loaded the code v 1.33
WiTcontroller connects to WiFi and I can connect to my DCC EX (Developer version 5.2.17) but within 30 seconds WiTcontroller disconnects.  At the same time, IF I have Engine Driver running on my tablet, that also gets disconnected at the same time.  I have been running this version of DCC EX and Engine Driver the last few weeks and no problem.
It's only since adding the WiTcontroller and within 30 seconds of it connecting do I see these disconnects.
If I start the controller and leave it connected to the WiFi but NOT connected to DCC EX, it just sits at the screen for the witServer IP:Port

I tried to find version 1.06 which is mentioned on the GitHub page that is stable, but I don't seem to be able to find it.
I am more than happy to assist in testing wherever possible.
I am running an Ethernet shield on the DCC EX, not a WiFi shield.  Engine Driver on the tablet has been working great with this setup.
The board for the WiTcontroller is a WEMOS Lite (AliExpress).
Any assistance would be great.
Kind regards
Barry.

flash62au, 2024-02-20:
Sorry, I completely missed your message here.
Please contact me on Discord and I will work with you.
https://discord.gg/3mxXmrCh

flash62au (Peter A)

2wheelsnz, 2024-02-21:
My bad,  I reached out on Discord and you helped solve the issue.  I did say I would come back to close this ticket but I forgot.  Sorry about that.  An update at this time is that it has been working flawlessly since the initial issue.  So once again, many thanks for your help.  Kind regards  Barry.

Closed 2024-02-21.

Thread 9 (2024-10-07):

problem with latching with function 2 horn

renegad84, 2024-10-07:
When change in config_buttons.h  define latching is true, on all buttons where changed latching working but on #define ADDITIONAL_BUTTON_2_LATCHING true  not working its stay momentary when pressed.
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

flash62au, 2024-10-07:
are you using JMRI?

renegad84, 2024-10-07:
yes and dcc-ex... on both is same

flash62au, 2024-10-07:
a) What version of WitController are you using?
b) What command to you have assigned to **CHOSEN_ADDITIONAL_BUTTON_2_FUNCTION** ?

Can I get you contact me on Discord.  It will be a lot easier to work through this.
https://discord.gg/qtsFHwSM
Either post on the '**wifi-throttle**' channel or DM me --- **flash62au (Peter A)**

flash62au, 2024-10-08:
Sorry, I just realised that you posted an image your button_config.

You don't have anything assigned to CHOSEN_ADDITIONAL_BUTTON_2_FUNCTION   It can do anything.
ADDITIONAL_BUTTON_2_LATCHING only comes into play if you are using the 6 additional optional buttons.

Do you just mean **Function 2** ?

renegad84, 2024-10-08:
yes function 2 or F2

flash62au, 2024-10-08:
If you have a roster entry for the loco it obeys whatever is in the roster entry. Otherwise it uses the defaults.

In JMRI, in the wiThrottle preferences, you can make F2 default to latching.
For DCC-EX you should be able to create a default roster entry, Address zero (0) and set the labels and latching to be whatever you want.

My alpha versions of Engine Driver has the ability to completely override the default labels and latching.  But they are not on the Play Store yet.

renegad84, 2024-10-08:
Thank you for help, sorry for bothering you.

flash62au, 2024-10-08:
no bother :-)
You're welcome.

Closed 2024-10-23.

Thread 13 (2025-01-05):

Compile problems

egstubbe, 2025-01-05:
To start sorry for any improper usage of my issue info.
Compile gets to lines 2781-2783 and fails and stops with errors.
will try to paste section where compile fails in code and console error output.
[line errors.pdf](https://github.com/user-attachments/files/18309360/line.errors.pdf)
[Console errors.pdf](https://github.com/user-attachments/files/18309361/Console.errors.pdf)
Thankyou Ed.
Sorry if I messed this up.

flash62au, 2025-01-05:
a) Which version of WiTController are you using?  (see the top of static.h)
b) Which version of the withrottleProtocol library are you using?  (look in the library manager in the Arduino ID or VSC)

egstubbe, 2025-01-05:
I followed the current instructions and matched the versions.WiTController V1.82withrottleProtocol V1.1.14

    On Sunday, January 5, 2025 at 12:42:36 AM CST, Peter Akers ***@***.***> wrote:

a) Which version of WiTController are you using? (see the top of static.h)
b) Which version of the withrottleProtocol library are you using? (look in the library manager in the Arduino IDE or VSC)

—
Reply to this email directly, view it on GitHub, or unsubscribe.
You are receiving this because you authored the thread.Message ID: ***@***.***>

flash62au, 2025-01-06:
As per the notes in the readme...
   * WiTcontroller version 1.82 or later requires WiThrottleProtocol version 1.1.26

egstubbe, 2025-01-06:
Sorry Peter while i was waiting for your response i updated version to 1.1.27 "current".I missed the "or later if available" part late last night.Now it compiles ok have to wait for my hardware to show up at the end of January to download.I followed instructions on GitHub and did not read the Readme file my bad habit "me bad".One last question i can not locate the "WiFi.h or the ESPmDNS.h files are they visible anywhere?Thank you for your prompt reply sorry for my mistake i have to learn to read the readme files firstalso thank you for your work on this project.Ed
    On Sunday, January 5, 2025 at 06:55:22 PM CST, Peter Akers ***@***.***> wrote:

As per the notes in the readme...

   - WiTcontroller version 1.82 or later requires WiThrottleProtocol version 1.1.26

—
Reply to this email directly, view it on GitHub, or unsubscribe.
You are receiving this because you authored the thread.Message ID: ***@***.***>

flash62au, 2025-01-06:
nw.
WiFi.h and ESPmDNS.h are installed automatically as part of the ESP32 Boards library.  (They are buried away in a subfolder somewhere.)
You do not need to do anything other than installing the ESP32 Boards library to get them.

 This is also explained in the readme.

egstubbe, 2025-01-06:
Thanks again for your help i did read that but wanted to try and verify it i assume it wouldnot compile with out them.You have the fastest response i have ever seen you must put your soul into it.This project along with the DCCEX station has me excited i was a Electronics Techbut still weak in the software part it.Do you have any ideas for a book to start on the c language?Have a great night.Ed. 
    On Sunday, January 5, 2025 at 07:47:28 PM CST, Peter Akers ***@***.***> wrote:

nw.
WiFi.h and ESPmDNS.h are installed automatically as part of the ESP32 Boards library. (They are buried away in a subfolder somewhere.)
You do not need to do anything other than installing the ESP32 Boards library to get them.

This is also explained in the readme.

—
Reply to this email directly, view it on GitHub, or unsubscribe.
You are receiving this because you authored the thread.Message ID: ***@***.***>

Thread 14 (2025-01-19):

Function 31 does not work if...

energiebrand, 2025-01-19:
It seems that at least Function 31 does not work if it is selected by:

-*
- 0
- #List
- #Pg
- #Pg
- #Pg
- #Pg
- 1  -> in my case 31 = Sound fader does not work

If I select the Function 31 directly it works:
-*
-0
-31#  -> now sound will be faded

Maybe also other Function >28 will not work(?)

flash62au, 2025-01-19:
F31 works correctly for me.|

a) Which version of WitController are you using?
b) If you are you using JMRI... Which Version?
c) If not, what Command Station / WiThrottle server are you using?

Peter

energiebrand, 2025-01-20:
- WitController release 1.84
- JMRI 5.10 (Throttle fuction... 31 working)
- DCC-EX Nucleo 5.5.7

Tested again today and it's behaviour is like described above.
F31 is working from JMRI throttle and in WiTcontroller if selected via:
-*
-0 Function
- 31#

but not via
-*
-0 Function
-# List
-# # # #
-1 (=31 Sound fader)

flash62au, 2025-01-20:
Can you provide the .xml file of the loco you have the problem with.

Peter

BTW.  It would probably be easier if you email me directly at   akersp62@gamil.com

energiebrand, 2025-01-20:
send you a mail and an XML file...

flash62au, 2025-01-20:
sorry.. I had a typo in my address
it is   akersp62@gmail.com

energiebrand, 2025-01-20:
after consulting the developer our understanding is that the behaviour could be a problem of the DCC-EX code for NUCLEO CS. Therefore this issue can be closed here.

Closed 2025-01-20.

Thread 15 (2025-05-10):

Config_Buttons.h Changes not Uploading

DaveSil1973, 2025-05-10:
Having just purchased a DCC-EX CSB1 I came across this page for the WiTcontroller and thought why not try it using the components specified. All seemed to be good following the instructions for WiTcontroller v1.92 except when changing the config_buttons.h file as below using Arduino IDE 1.8.19:

#define ENCODER_ROTATION_CLOCKWISE_IS_INCREASE_SPEED                     true (changed from false)

#define ROTARY_ENCODER_DEBOUNCE_TIME     500 (changed from 200)

/#define SPEED_STEP                       1 (changed from 4)

Having compiled the .INO file and uploaded it to the WEMOS, including erasing the flash memory first, none of the changes are effective: you still have to turn the encoder anti-clockwise to increase speed and the speed steps remain at 4.

I have esp32 3.2.0 installed but have tried with 2.0.11 which made no difference.

I have opened the saved config file in Visual Studio Code which confirms the changes I made have been saved. This being my first foray into the arduino world I am wondering what I am doing wrong.

Note that changes to config_network.h were sucessfully loaded.

Any help gratefully received.

David.

flash62au, 2025-05-10:
Please email me your full config_buttons.h
Akersp62 @ gmail.com   (remove the spaces)

Peter

DaveSil1973, 2025-05-10:
Hi Peter

File attached as requested.

Kind regards

David

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

flash62au, 2025-05-10:
Hi,
I haven't received any file.

Please email it to me at akersp62@gmail.com. Or open GitHub and attach it there.

Don't reply to the email from GitHub. Attaching a file that way does not seem to work.

Peter

Closed 2025-05-12.

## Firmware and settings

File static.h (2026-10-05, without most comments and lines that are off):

const String appVersion = "v1.120";
#ifndef CUSTOM_APPNAME
   const String appName = "WiTcontroller";
#else
   const String appName = CUSTOM_APPNAME;
#endif
   #define DEVICE_NAME "WiTcontroller"
    #define ROTARY_ENCODER_A_PIN 12  // to DT
    #define ROTARY_ENCODER_B_PIN 14  // to CLK
    #define ROTARY_ENCODER_BUTTON_PIN 13  // to SW
    #define ROTARY_ENCODER_VCC_PIN -1
    #define ROTARY_ENCODER_STEPS 2 //depending on your encoder - try 1,2 or 4 to get expected behaviour
    #define ROW_NUM     4
    #define COLUMN_NUM  3
    #define KEYPAD_KEYS  {'1', '2', '3'}, {'4', '5', '6'}, {'7', '8', '9'}, {'*', '0', '#'}
    #define KEYPAD_ROW_PINS    {19, 18, 17, 16}
    #define KEYPAD_COLUMN_PINS { 4, 0, 2}
char keys[ROW_NUM][COLUMN_NUM] = {KEYPAD_KEYS};
byte pin_rows[ROW_NUM]      = KEYPAD_ROW_PINS; // GIOP19, GIOP18, GIOP5, GIOP17 connect to the row pins
byte pin_column[COLUMN_NUM] = KEYPAD_COLUMN_PINS;   // GIOP16, GIOP4, GIOP0 connect to the column pins
Keypad keypad = Keypad( makeKeymap(keys), pin_rows, pin_column, ROW_NUM, COLUMN_NUM );
    #define KEYPAD_DEBOUNCE_TIME 10
    #define KEYPAD_HOLD_TIME 200
   #define USE_WIFI_COUNTRY_CODE false
   #define COUNTRY_CODE "01"
   #define ENFORCED_COUNTRY_CODE false
   #define MENU_TEXT_MENU                      "* Menu                # Key Defs"
   #define MENU_TEXT_MENU_HASH_IS_FUNCTIONS    "* Menu                          # Fn"
   #define MENU_TEXT_FINISH                    "                        # Finish"
   #define MENU_TEXT_CANCEL                    "* Cancel"
   #define MENU_TEXT_SHOW_DIRECT               "                  # Show Direct"
   #define MENU_TEXT_ROSTER                    "* Cancel      0-9      #Pg"
   #define MENU_TEXT_TURNOUT_LIST              "* Cancel      0-9      #Pg"
   #define MENU_TEXT_ROUTE_LIST                "* Cancel      0-9      #Pg"
   #define MENU_TEXT_FUNCTION_LIST             "* Cancel      0-9      #Pg"
   #define MENU_TEXT_SELECT_WIT_SERVICE        "0-4 * Refrsh # Entry E.btn OFF"
   #define MENU_TEXT_SELECT_WIT_ENTRY          "0-9   * Back  # Go   E.btn OFF"
   #define MENU_TEXT_SELECT_SSIDS              "0-9     # Search      E.btn OFF"
   #define MENU_TEXT_SELECT_SSIDS_FROM_FOUND   "0-4    9 List  # Pg   E.btn OFF"
   #define MENU_TEXT_ENTER_SSID_PASSWORD       "E Chrs  E.btn Slct  # Go  * Bck"
const String menu_text[14] = {
  MENU_TEXT_MENU,
  MENU_TEXT_MENU_HASH_IS_FUNCTIONS,
  MENU_TEXT_FINISH,
  MENU_TEXT_CANCEL,
  MENU_TEXT_SHOW_DIRECT,
  MENU_TEXT_ROSTER,
  MENU_TEXT_TURNOUT_LIST,
  MENU_TEXT_ROUTE_LIST,
  MENU_TEXT_FUNCTION_LIST,
  MENU_TEXT_SELECT_WIT_SERVICE,
  MENU_TEXT_SELECT_WIT_ENTRY,
  MENU_TEXT_SELECT_SSIDS,
  MENU_TEXT_SELECT_SSIDS_FROM_FOUND,
  MENU_TEXT_ENTER_SSID_PASSWORD
};
const int menu_menu =                     0;
const int menu_menu_hash_is_functions =   1;
const int menu_finish =                   2;
const int menu_cancel =                   3;
const int menu_show_direct =              4;
const int menu_roster =                   5;
const int menu_turnout_list =             6;
const int menu_route_list =               7;
const int menu_function_list =            8;
const int menu_select_wit_service =       9;
const int menu_select_wit_entry =        10;
const int menu_select_ssids =            11;
const int menu_select_ssids_from_found = 12;
const int menu_enter_ssid_password =     13;
const int last_oled_screen_speed =            0;
const int last_oled_screen_roster =           1;
const int last_oled_screen_turnout_list =     2;
const int last_oled_screen_route_list =       3;
const int last_oled_screen_function_list =    4;
const int last_oled_screen_menu          =    5;
const int last_oled_screen_extra_submenu =    6;
const int last_oled_screen_all_locos =        7;
const int last_oled_screen_edit_consist =     8;
const int last_oled_screen_direct_commands =  9;
typedef enum ShowBattery {
    NONE = 0,
    ICON_ONLY = 1,
    ICON_AND_PERCENT = 2
} ShowBattery;
  #define DIRECT_COMMAND_LIST            "Direct Commands"
  #define DIRECTION_FORWARD_TEXT         "Fwd"
  #define DIRECTION_REVERSE_TEXT         "Rev"
  #define DIRECTION_FORWARD_TEXT_SHORT   ">"
  #define DIRECTION_REVERSE_TEXT_SHORT   "<"
  #define DIRECTION_REVERSE_INDICATOR    "'"
  #define MSG_START                     "Start"
  #define MSG_BROWSING_FOR_SERVICE      "Browsing for WiT services"
  #define MSG_BROWSING_FOR_SSIDS        "Browsing for SSIDs"
  #define MSG_NO_SSIDS_FOUND            "No SSIDs found"
  #define MSG_SSIDS_LISTED              "  SSIDs listed"
  #define MSG_SSIDS_FOUND               "    SSIDs found"
  #define MSG_BOUNJOUR_SETUP_FAILED     "Unable to setup Listener"
  #define MSG_NO_SERVICES_FOUND         "No services found"
  #define MSG_NO_SERVICES_FOUND_ENTRY_REQUIRED "Enter witServer IP:Port"
  #define MSG_SERVICES_FOUND            " Service(s) found"
  #define MSG_TRYING_TO_CONNECT         "Trying to Connect"
  #define MSG_CONNECTED                 "             Connected"
  #define MSG_CONNECTING                "             Connecting..."
   #define MSG_ADDRESS_LABEL            "IP address: "
   #define MSG_CONNECTION_FAILED        "Connection failed"
   #define MSG_DISCONNECTED             "Disconnected"
   #define MSG_AUTO_SLEEP               "Waited too long for Select"
   #define MSG_BATTERY_SLEEP            "Battery critically low"
   #define MSG_START_SLEEP              "Shutting Down.        E.btn ON"
   #define MSG_THROTTLE_NUMBER          "          Throttle #"
   #define MSG_NO_LOCO_SELECTED         "        No Loco selected"
   #define MSG_ENTER_PASSWORD           "Enter Password"
   #define MSG_GUESSED_EX_CS_WIT_SERVER "'Guessed' EX-CS WiT server"
   #define MSG_BYPASS_WIT_SERVER_SEARCH     "Bypass WiT server search"
   #define MSG_NO_FUNCTIONS             "Function List - No Functions"
   #define MSG_HEARTBEAT_CHECK_ENABLED  "Heartbeat Check Enabled"
   #define MSG_HEARTBEAT_CHECK_DISABLED "Heartbeat Check Disabled"
   #define MSG_RECEIVING_SERVER_DETAILS  "Getting data from server"
const String label_track_power = "TRK";
const int glyph_heartbeat_off = 0x00b7;
const int glyph_track_power = 0x00eb;
const int glyph_guest_mode = 0x00ca;
const int glyph_speed_step = 0x00d6;
#define SLEEP_REASON_COMMAND 0
#define SLEEP_REASON_INACTIVITY 1
#define SLEEP_REASON_BATTERY 2
#define KEYPAD_USE_OPERATION 0
#define KEYPAD_USE_SELECT_SSID 1
#define KEYPAD_USE_SELECT_SSID_FROM_FOUND 2
#define KEYPAD_USE_SELECT_WITHROTTLE_SERVER 3
#define KEYPAD_USE_ENTER_WITHROTTLE_SERVER 4
#define KEYPAD_USE_SELECT_ROSTER 5
#define KEYPAD_USE_SELECT_TURNOUTS_THROW 6
#define KEYPAD_USE_SELECT_TURNOUTS_CLOSE 7
#define KEYPAD_USE_SELECT_ROUTES 8
#define KEYPAD_USE_SELECT_FUNCTION 9
#define KEYPAD_USE_ENTER_SSID_PASSWORD 10
#define KEYPAD_USE_EDIT_CONSIST 11
#define ENCODER_USE_OPERATION 0
#define ENCODER_USE_SSID_PASSWORD 1
#define CONNECTION_STATE_DISCONNECTED 0
#define CONNECTION_STATE_CONNECTED 1
#define CONNECTION_STATE_SELECTION_REQUIRED 2
#define CONNECTION_STATE_ENTRY_REQUIRED 3
#define CONNECTION_STATE_SELECTED 4
#define CONNECTION_STATE_PASSWORD_ENTRY 5
#define CONNECTION_STATE_ENTERED 6
#define SSID_CONNECTION_SOURCE_LIST 0
#define SSID_CONNECTION_SOURCE_BROWSE 1
#define CMD_FUNCTION 0
#define MAX_LOCOS     10  // maximum number of locos that can be added to the consist
#define MAX_FUNCTIONS 32
   #define CONSIST_RELEASE_BY_INDEX true
   #define MENU_ITEM_TEXT_TITLE_FUNCTION               "Function"
   #define MENU_ITEM_TEXT_TITLE_ADD_LOCO               "Add Loco"
   #define MENU_ITEM_TEXT_TITLE_DROP_LOCO              "Drop Loco"
   #define MENU_ITEM_TEXT_TITLE_TOGGLE_DIRECTION       "Toggle Dir"
   #define MENU_ITEM_TEXT_TITLE_SPEED_STEP_MULTIPLIER  "X SpeedStep"
   #define MENU_ITEM_TEXT_TITLE_THROW_POINT            "Throw Point"
   #define MENU_ITEM_TEXT_TITLE_CLOSE_POINT            "Close Point"
   #define MENU_ITEM_TEXT_TITLE_ROUTE                  "Route"
   #define MENU_ITEM_TEXT_TITLE_TRACK_POWER            "Trk Power"
   #define MENU_ITEM_TEXT_TITLE_EXTRAS                 "Extras"
   #define MENU_ITEM_TEXT_TITLE_HEARTBEAT              "Heartbeat"
   #define MENU_ITEM_TEXT_TITLE_EDIT_CONSIST           "Edit Consist Facing"
   #define MENU_TEXT_TITLE_TBA                         ""
   #define MENU_ITEM_TEXT_MENU_FUNCTION               "no+# Select   * Cancel  # List"
   #define MENU_ITEM_TEXT_MENU_ADD_LOCO               "addr+# Add * Cancel # Roster"
   #define MENU_ITEM_TEXT_MENU_DROP_LOCO              "addr+# One   * Cancel    # All"
   #define MENU_ITEM_TEXT_MENU_DROP_LOCO_BY_INDEX     "no+# One     * Cancel    # All"
#if CONSIST_RELEASE_BY_INDEX
   #define MENU_ITEM_TEXT_MENU_DROP_LOCO_REAL MENU_ITEM_TEXT_MENU_DROP_LOCO_BY_INDEX
#else
   #define MENU_ITEM_TEXT_MENU_DROP_LOCO_REAL MENU_ITEM_TEXT_MENU_DROP_LOCO
#endif
   #define MENU_ITEM_TEXT_MENU_TOGGLE_DIRECTION       "# Toggle                      "
   #define MENU_ITEM_TEXT_MENU_SPEED_STEP_MULTIPLIER  "* Cancel                # Toggle"
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

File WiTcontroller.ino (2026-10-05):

/**
 * This app turns an ESP32 into a dedicated Model Railway Controller for use
 * with JMRI or any wiThrottle server.

  Instructions:
  - Refer to the readme at https://github.com/flash62au/WiTcontroller
 */

#include <string>

// Use the Arduino IDE 'Boards' Manager to get these libraries
// They will be installed with the 'ESP32' Board library
// DO NOT DOWNLOAD THEM DIRECTLY!!!
#include <WiFi.h>                 // https://github.com/espressif/arduino-esp32/tree/master/libraries/WiFi     GPL 2.1
#include <ESPmDNS.h>              // https://github.com/espressif/arduino-esp32/blob/master/libraries/ESPmDNS  GPL 2.1
#include <esp_wifi.h>             // https://git.liberatedsystems.co.uk/jacob.eva/arduino-esp32/src/branch/master/tools/sdk/esp32s2/include/esp_wif  GPL 2.0
#include <Preferences.h>

// ----------------------

// use the Arduino IDE 'Library' Manager to get these libraries
#include <Keypad.h>               // https://www.arduinolibraries.info/libraries/keypad                        GPL 3.0
#include <U8g2lib.h>              // https://github.com/olikraus/u8g2  (Just get "U8g2" via the Arduino IDE Library Manager)   new-bsd
#include <WiThrottleProtocol.h>   // https://github.com/flash62au/WiThrottleProtocol                           Creative Commons 4.0  Attribution-ShareAlike
#include <AiEsp32RotaryEncoder.h> // https://github.com/igorantolic/ai-esp32-rotary-encoder                    GPL 2.0

// this library is included with the WiTcontroller code
#include "Pangodream_18650_CL.h"  // https://github.com/pangodream/18650CL                                     Copyright (c) 2019 Pangodream

// create these files by copying the example files and editing them as needed
#include "config_buttons.h"      // keypad buttons assignments
#include "config_network.h"      // LAN networks (SSIDs and passwords)

// DO NOT ALTER these files
#include "static.h"
#include "actions.h"
#include "WiTcontroller.h"

#if WITCONTROLLER_DEBUG == 0
 #define debug_print(params...) Serial.print(params)
 #define debug_println(params...) Serial.print(params); Serial.print(" ("); Serial.print(millis()); Serial.println(")")
 #define debug_printf(params...) Serial.printf(params)
#else
 #define debug_print(...)
 #define debug_println(...)
 #define debug_printf(...)
#endif
int debugLevel = DEBUG_LEVEL;


// *********************************************************************************
// non-volatile storage

Preferences nvsPrefs;
bool nvsInit = false;
bool nvsPrefsSaved = false;
bool preferencesRead = false;
String retrievedSsid = "";
String retrievedPassword = "";

// *********************************************************************************

int keypadUseType = KEYPAD_USE_OPERATION;
int encoderUseType = ENCODER_USE_OPERATION;
int encoderButtonAction = ENCODER_BUTTON_ACTION;

bool menuCommandStarted = false;
String menuCommand = "";
bool menuIsShowing = false;

String startupCommands[4] = {STARTUP_COMMAND_1, STARTUP_COMMAND_2, STARTUP_COMMAND_3, STARTUP_COMMAND_4};

String oledText[18] = {"", "", "", "", "", "", "", "", "", "", "", "", "", "", "", "", "", ""};
bool oledTextInvert[18] = {false, false, false, false, false, false, false, false, false, 
                           false, false, false, false, false, false, false, false, false};

int currentSpeed[6];   // set to maximum possible (6)
Direction currentDirection[6];   // set to maximum possible (6)
int speedStepCurrentMultiplier = DEFAULT_SPEED_STEP_MULTIPLIER;

TrackPower trackPower = PowerUnknown;
String turnoutPrefix = "";
String routePrefix = "";

// encoder variables
bool circleValues = true;
int encoderValue = 0;
int lastEncoderValue = 0;

// throttle pot values
bool useRotaryEncoderForThrottle = USE_ROTARY_ENCODER_FOR_THROTTLE;
int throttlePotPin = THROTTLE_POT_PIN;
bool throttlePotUseNotches = THROTTLE_POT_USE_NOTCHES;
int throttlePotNotchValues[] = THROTTLE_POT_NOTCH_VALUES; 
int throttlePotNotchSpeeds[] = THROTTLE_POT_NOTCH_SPEEDS;
int throttlePotNotch = 0;
int throttlePotTargetSpeed = 0;
int lastThrottlePotValue = 0;
int lastThrottlePotHighValue = 0;  // highest of the most recent
int lastThrottlePotValues[] = {0, 0, 0, 0, 0};
int lastThrottlePotReadTime = -1;

// battery test values
bool useBatteryTest = USE_BATTERY_TEST;
#if USE_BATTERY_TEST
  #if USE_BATTERY_PERCENT_AS_WELL_AS_ICON
    ShowBattery showBatteryTest = ICON_AND_PERCENT;
  #else 
    ShowBattery showBatteryTest = ICON_ONLY;
  #endif
#else
  ShowBattery showBatteryTest = NONE;
#endif
bool useBatteryPercentAsWellAsIcon = USE_BATTERY_PERCENT_AS_WELL_AS_ICON;
int lastBatteryTestValue = 100; 
int lastBatteryAnalogReadValue = 0;
double lastBatteryCheckTime = -10000;
#if USE_BATTERY_TEST
  Pangodream_18650_CL BL(BATTERY_TEST_PIN,BATTERY_CONVERSION_FACTOR);
#endif

// server variables
// bool ssidConnected = false;
String selectedSsid = "";
String selectedSsidPassword = "";
int ssidConnectionState = CONNECTION_STATE_DISCONNECTED;

// ssid password entry
String ssidPasswordEntered = "";
bool ssidPasswordChanged = true;
char ssidPasswordCurrentChar = ssidPasswordBlankChar; 
bool haveTriedGuessedDccexPassword = false;

IPAddress selectedWitServerIP;
int selectedWitServerPort = 0;
String selectedWitServerName ="";
int noOfWitServices = 0;
int witConnectionState = CONNECTION_STATE_DISCONNECTED;
String serverType = "";

//found wiThrottle servers
IPAddress foundWitServersIPs[maxFoundWitServers];
int foundWitServersPorts[maxFoundWitServers];
String foundWitServersNames[maxFoundWitServers];
int foundWitServersCount = 0;
bool autoConnectToFirstDefinedServer = AUTO_CONNECT_TO_FIRST_DEFINED_SERVER;
bool autoConnectToFirstWiThrottleServer = AUTO_CONNECT_TO_FIRST_WITHROTTLE_SERVER;
int outboundCmdsMininumDelay = OUTBOUND_COMMANDS_MINIMUM_DELAY;
bool commandsNeedLeadingCrLf = SEND_LEADING_CR_LF_FOR_COMMANDS;

//found ssids
String foundSsids[maxFoundSsids];
long foundSsidRssis[maxFoundSsids];
bool foundSsidsOpen[maxFoundSsids];
int foundSsidsCount = 0;
int ssidSelectionSource;
double startWaitForSelection;

// wit Server ip entry
String witServerIpAndPortConstructed = "###.###.###.###:#####";
String witServerIpAndPortEntered = DEFAULT_IP_AND_PORT;
bool witServerIpAndPortChanged = true;

// roster variables
int rosterSize = 0;
int rosterIndex[maxRoster]; 
String rosterName[maxRoster]; 
int rosterAddress[maxRoster];
char rosterLength[maxRoster];
char rosterSortStrings[maxRoster][14]; 
char* rosterSortPointers[maxRoster]; 
int rosterSortedIndex[maxRoster]; 

int page = 0;
int functionPage = 0;
bool functionHasBeenSelected = false;
int functionPageSize = SHOW_LONGER_FUNCTION_LABELS ? 5 :10;

// Broadcast msessage
String broadcastMessageText = "";
long broadcastMessageTime = 0;
long lastReceivingServerDetailsTime = 0;

// remember oLED state
int lastOledScreen = 0;
String lastOledStringParameter = "";
int lastOledIntParameter = 0;
bool lastOledBoolParameter = false;
TurnoutAction lastOledTurnoutParameter = TurnoutToggle;

// turnout variables
int turnoutListSize = 0;
int turnoutListIndex[maxTurnoutList]; 
String turnoutListSysName[maxTurnoutList]; 
String turnoutListUserName[maxTurnoutList];
int turnoutListState[maxTurnoutList];

// route variables
int routeListSize = 0;
int routeListIndex[maxRouteList]; 
String routeListSysName[maxRouteList]; 
String routeListUserName[maxRouteList];
int routeListState[maxRouteList];

//**************************************************************************************
// Guest Mode - custom function not included with original code. When two of the additional 
// buttons are pressed together and held for a few seconds, "guest mode" is enabled.
// This illuminates an optional LED indicator and disables any keypad inputs as well as the "next throttle" 
// function. I added this primarily so that children can use the throttle and quick function buttons, 
// without accidentally entering any menus or changing settings. To exit guest mode, press and hold 
// the lights and sound buttons again.
//
// Will - Coventry Railworks
//**************************************************************************************
bool guestModeActive = false;
bool guestModeGestureInProgress = false;
bool guestModeGestureProcessed = false;
unsigned long guestModeHoldStartTime = 0;
const unsigned long guestModeHoldDuration = GUEST_MODE_HOLD_DURATION; // milliseconds - confirmed two-button hold to toggle Guest Mode
const unsigned long gesturePartnerWindow = GESTURE_PARTNER_WINDOW;    // milliseconds - how long we wait to see if the other button joins

bool guestModeFunctionPending[2] = {false, false};
unsigned long guestModeFunctionPendingStartTime[2] = {0, 0};

bool guestModeFunctionFiredThisPress[2] = {false, false};

//**************************************************************************************
// function button searches
String functionSearchLabels[MAX_FUNCTION_SEARCH][2] = FUNCTION_SEARCH_LABELS;
int functionSearchIds[MAX_FUNCTION_SEARCH] = FUNCTION_SEARCH_IDS;
int functionSearchFoundFunctionNumber[MAX_FUNCTION_SEARCH];

// function states
bool functionStates[6][MAX_FUNCTIONS];   // set to maximum possible (6 throttles)

// function labels
String functionLabels[6][MAX_FUNCTIONS];   // set to maximum possible (6 throttles)

// consist function follow
int functionFollow[6][MAX_FUNCTIONS];   // set to maximum possible (6 throttles)

// speedstep
int currentSpeedStep[6];   // set to maximum possible (6 throttles)

// throttle
int currentThrottleIndex = 0;
char currentThrottleIndexChar = '0';
int maxThrottles = MAX_THROTTLES;

int heartbeatPeriod = DEFAULT_HEARTBEAT_PERIOD; // default to 10 seconds
long lastServerResponseTime;  // seconds since start of Arduino
bool heartbeatCheckEnabled = HEARTBEAT_ENABLED;

// used to stop speed bounces
long lastSpeedSentTime = 0;
int lastSpeedSent = 0;
// int lastDirectionSent = -1;
int lastSpeedThrottleIndex = 0;

bool dropBeforeAcquire = DROP_BEFORE_ACQUIRE;

// don't alter the assignments here
// alter them in config_buttons.h

const char* deviceName = DEVICE_NAME;

static unsigned long rotaryEncoderButtonLastTimePressed = 0;
const int rotaryEncoderButtonEncoderDebounceTime = ROTARY_ENCODER_DEBOUNCE_TIME;   // in miliseconds

const bool encoderRotationClockwiseIsIncreaseSpeed = ENCODER_ROTATION_CLOCKWISE_IS_INCREASE_SPEED;
// false = Counterclockwise  true = clockwise

const bool toggleDirectionOnEncoderButtonPressWhenStationary = TOGGLE_DIRECTION_ON_ENCODER_BUTTON_PRESSED_WHEN_STATIONAY;
// true = if the locos(s) are stationary, clicking the encoder button will toggle the direction

const bool speedZeroOnDirectionChange = SPEED_ZERO_ON_DIRECTION_CHANGE;

//4x3 keypad only uses 0-9
//4x4 uses all 14 
int buttonActions[14] = { CHOSEN_KEYPAD_0_FUNCTION,
                          CHOSEN_KEYPAD_1_FUNCTION,
                          CHOSEN_KEYPAD_2_FUNCTION,
                          CHOSEN_KEYPAD_3_FUNCTION,
                          CHOSEN_KEYPAD_4_FUNCTION,
                          CHOSEN_KEYPAD_5_FUNCTION,
                          CHOSEN_KEYPAD_6_FUNCTION,
                          CHOSEN_KEYPAD_7_FUNCTION,
                          CHOSEN_KEYPAD_8_FUNCTION,
                          CHOSEN_KEYPAD_9_FUNCTION,
                          CHOSEN_KEYPAD_A_FUNCTION,
                          CHOSEN_KEYPAD_B_FUNCTION,
                          CHOSEN_KEYPAD_C_FUNCTION,
                          CHOSEN_KEYPAD_D_FUNCTION
};

// text that will appear when you press #
const String directCommandText[4][3] = {
    {CHOSEN_KEYPAD_1_DISPLAY_NAME, CHOSEN_KEYPAD_2_DISPLAY_NAME, CHOSEN_KEYPAD_3_DISPLAY_NAME},
    {CHOSEN_KEYPAD_4_DISPLAY_NAME, CHOSEN_KEYPAD_5_DISPLAY_NAME, CHOSEN_KEYPAD_6_DISPLAY_NAME},
    {CHOSEN_KEYPAD_7_DISPLAY_NAME, CHOSEN_KEYPAD_8_DISPLAY_NAME, CHOSEN_KEYPAD_9_DISPLAY_NAME},
    {CHOSEN_KEYPAD_DISPLAY_PREFIX, CHOSEN_KEYPAD_0_DISPLAY_NAME, CHOSEN_KEYPAD_DISPLAY_SUFIX}
};

bool oledDirectCommandsAreBeingDisplayed = false;
#ifdef HASH_SHOWS_FUNCTIONS_INSTEAD_OF_KEY_DEFS
  bool hashShowsFunctionsInsteadOfKeyDefs = HASH_SHOWS_FUNCTIONS_INSTEAD_OF_KEY_DEFS;
#else
  bool hashShowsFunctionsInsteadOfKeyDefs = false;
#endif

//optional additional buttons
#if !USE_NEW_ADDITIONAL_BUTTONS_FORMAT
  int maxAdditionalButtons = MAX_ADDITIONAL_BUTTONS;
  int additionalButtonPin[MAX_ADDITIONAL_BUTTONS] =          ADDITIONAL_BUTTONS_PINS;
  int additionalButtonType[MAX_ADDITIONAL_BUTTONS] =         ADDITIONAL_BUTTONS_TYPE;
  int additionalButtonActions[MAX_ADDITIONAL_BUTTONS] = {
                            CHOSEN_ADDITIONAL_BUTTON_0_FUNCTION,
                            CHOSEN_ADDITIONAL_BUTTON_1_FUNCTION,
                            CHOSEN_ADDITIONAL_BUTTON_2_FUNCTION,
                            CHOSEN_ADDITIONAL_BUTTON_3_FUNCTION,
                            CHOSEN_ADDITIONAL_BUTTON_4_FUNCTION,
                            CHOSEN_ADDITIONAL_BUTTON_5_FUNCTION,
                            CHOSEN_ADDITIONAL_BUTTON_6_FUNCTION
  };
  int additionalButtonLatching[MAX_ADDITIONAL_BUTTONS] = {
                            ADDITIONAL_BUTTON_0_LATCHING,
                            ADDITIONAL_BUTTON_1_LATCHING,
                            ADDITIONAL_BUTTON_2_LATCHING,
                            ADDITIONAL_BUTTON_3_LATCHING,
                            ADDITIONAL_BUTTON_4_LATCHING,
                            ADDITIONAL_BUTTON_5_LATCHING,
                            ADDITIONAL_BUTTON_6_LATCHING
  };

  unsigned long lastAdditionalButtonDebounceTime[MAX_ADDITIONAL_BUTTONS];  // the last time the output pin was toggled
  bool additionalButtonRead[MAX_ADDITIONAL_BUTTONS];
  bool additionalButtonLastRead[MAX_ADDITIONAL_BUTTONS];
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
void loop() {
  
  if (ssidConnectionState != CONNECTION_STATE_CONNECTED) {
    // connectNetwork();
    ssidsLoop();
    checkForShutdownOnNoResponse();
  } else {  
    if (witConnectionState != CONNECTION_STATE_CONNECTED) {
      witServiceLoop();
      checkForShutdownOnNoResponse();
    } else {
      static unsigned long lastCheck = 0;

      if (millis() - lastCheck >= 100) {
        lastCheck = millis();
        wiThrottleProtocol.check();
      }

      setLastServerResponseTime(false);

      if ( (lastServerResponseTime+(heartbeatPeriod*4) < millis()/1000) 
      && (heartbeatCheckEnabled) ) {
        debug_print("Disconnected - Last:");  debug_print(lastServerResponseTime); debug_print(" Current:");  debug_println(millis()/1000);
        reconnect();
      }
    }
  }
  // char key = keypad.getKey();
  keypad.getKey(); 
  if (useRotaryEncoderForThrottle) { rotary_loop(); }
  else { throttlePot_loop(); }
  additionalButtonLoop(); 

  if (useBatteryTest) { batteryTest_loop(); }

	// debug_println("loop:" );
}

// *********************************************************************************
//  Key press and Menu
// *********************************************************************************

void doKeyPress(char key, bool pressed) {
  if (guestModeActive && !GUEST_MODE_ALLOW_DIRECT_KEYBOARD_COMMANDS) return;

  debug_print("doKeyPress(): key: "); debug_print(key); debug_print(" keypadUseType: ");debug_println(keypadUseType);

  if (pressed)  { //pressed
    debug_println("doKeyPress(): pressed"); 
    switch (keypadUseType) {
      case KEYPAD_USE_OPERATION:
        debug_print("doKeyPress(): key operation... "); debug_println(key);

        switch (key) {
          case '*':  // menu command
            menuCommand = "";
            if (menuCommandStarted) { // then cancel the menu
              resetMenu();
              writeOledSpeed();
            } else {
              if (guestModeActive) return;  // will react here if GUEST_MODE_ALLOW_DIRECT_KEYBOARD_COMMANDS is true

              menuCommandStarted = true;
              debug_println("doKeyPress(): Command started");
              writeOledMenu("", true);
            }
            break;

          case '#': // end of command
            debug_print("doKeyPress(): end of command... "); debug_print(key); debug_print ("  :  "); debug_println(menuCommand);
            if ((menuCommandStarted) && (menuCommand.length()>=1)) {
              doMenu();
            } else {
              if (!hashShowsFunctionsInsteadOfKeyDefs) {
                if (!oledDirectCommandsAreBeingDisplayed) {
                  writeOledDirectCommands();
                } else {
                  oledDirectCommandsAreBeingDisplayed = false;
                  writeOledSpeed();
                }
              } else {
                writeOledFunctionList(""); 
              }
            }
            break;

          case '0': case '1': case '2': case '3': case '4': 
          case '5': case '6': case '7': case '8': case '9': 
          {
            debug_print("doKeyPress(): number... "); debug_print(key); 
            debug_print ("  cmd: '"); debug_println(menuCommand); 
            debug_print("' : "); debug_println(menuCharsRequired[menuCommand.substring(0,1).toInt()]);

            int index0 = key-48;
            int index1 = 0;
            if (menuCommand.length() >= 0) index1 = menuCommand.charAt(0)-48;
            int index2 = 0;
            if (menuCommand.length() >= 1) index2 = menuCommand.charAt(1)-48;

            if (menuCommandStarted) { // append to the string

              // if ( ((menuCommand.length() == 0) && (menuCharsRequired[key-48] == MENU_ITEM_TYPE_DIRECT_COMMAND))
              // || ((menuCommand.length() == 1) && (menuCharsRequired[menuCommand.charAt(0)-48] == MENU_ITEM_TYPE_SUB_MENU))
              // || ((menuCommand.length() == 1) && (menuCharsRequired[menuCommand.charAt(0)-48] == MENU_ITEM_TYPE_DIRECT_COMMAND))
              // || ((menuCommand.length() == 2) && (menuCharsRequired[menuCommand.charAt(1)-38] == MENU_ITEM_TYPE_DIRECT_COMMAND)) ) { 

              if ( ((menuCommand.length() == 0) 
                    && (menuCharsRequired[index0] == MENU_ITEM_TYPE_DIRECT_COMMAND))
              || ((menuCommand.length() == 1) 
                    &&  ( (menuCharsRequired[index1] == MENU_ITEM_TYPE_SUB_MENU)
                       || (menuCharsRequired[index1] == MENU_ITEM_TYPE_DIRECT_COMMAND) ))
              || ((menuCommand.length() == 2) 
                    &&  (menuCharsRequired[index1] != MENU_ITEM_TYPE_ONE_OR_MORE_CHARS)
                    &&  (menuCharsRequired[index2] == MENU_ITEM_TYPE_DIRECT_COMMAND)) 
              ) { 
                debug_println("doKeyPress(): MENU_ITEM_TYPE_DIRECT_COMMAND : ");
                menuCommand += key;
                doMenu();
              } else {
                if ((menuCharsRequired[index0] == MENU_ITEM_TYPE_SUB_MENU) 
                && (menuCommand.length() == 0)) {  // menu type needs only one char
                  debug_println("doKeyPress(): MENU_ITEM_TYPE_SUB_MENU : "); 
                  menuCommand += key;
                  writeOledMenu(menuCommand, false);
                // } else if ( (menuCharsRequired[index0] == MENU_ITEM_TYPE_SELECT_FROM_LIST) 
                //           && (menuCommand.length() == 0)) {  // menu type needs only one char
                //   debug_println("doKeyPress(): MENU_ITEM_TYPE_SELECT_FROM_LIST : "); 
                //   menuCommand += key;
                //   writeOledMenu(menuCommand, false);
                } else {  //menu type allows/requires more than one char
                  debug_println("doKeyPress(): MENU_ITEM_TYPE_ONE_OR_MORE_CHARS");
                  menuCommand += key;
                  writeOledMenu(menuCommand, true);
                }
              }
            } else {
              doDirectCommand(key, true);
            }
            break;
          }
          default:  // A, B, C, D
            doDirectCommand(key, true);
            break;
        }
        break;

      case KEYPAD_USE_ENTER_WITHROTTLE_SERVER:
        debug_print("doKeyPress(): key: Enter wit... "); debug_println(key);
        switch (key){
          case '0': case '1': case '2': case '3': case '4': 
          case '5': case '6': case '7': case '8': case '9':
            witEntryAddChar(key);
            break;
          case '*': // backspace
            witEntryDeleteChar(key);
            break;
          case '#': // end of command
            if (witServerIpAndPortEntered.length() == 17) {
              witConnectionState = CONNECTION_STATE_ENTERED;
            }
            break;
          default:  // do nothing 
            break;
        }

        break;

      case KEYPAD_USE_ENTER_SSID_PASSWORD:
        debug_print("doKeyPress(): key: Enter password... "); debug_println(key);
        switch (key){
          case '0': case '1': case '2': case '3': case '4': 
          case '5': case '6': case '7': case '8': case '9':
            ssidPasswordAddChar(key);
            break;
          case '*': // backspace
            ssidPasswordDeleteChar(key);
            break;
          case '#': // end of command
              selectedSsidPassword = ssidPasswordEntered;
              encoderUseType = ENCODER_USE_OPERATION;
              keypadUseType = KEYPAD_USE_OPERATION;
              ssidConnectionState = CONNECTION_STATE_SELECTED;
              saveSsidAndPasswordPreference();
            break;
          default:  // do nothing 
            break;
        }

        break;

      case KEYPAD_USE_SELECT_WITHROTTLE_SERVER:
        debug_print("doKeyPress(): key: Select wit... "); debug_println(key);
        switch (key){
          case '0': case '1': case '2': case '3': case '4':
            selectWitServer(key - '0');
            break;
          case '#': // show ip address entry screen
            witConnectionState = CONNECTION_STATE_ENTRY_REQUIRED;
            buildWitEntry();
            enterWitServer();
            break;
          case '*': // refresh
            MDNS.begin("WiTcontroller");
            witConnectionState = CONNECTION_STATE_DISCONNECTED;
            break;
          default:  // do nothing 
            break;
        }
        break;
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

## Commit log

2022-05-11 small ESP32 and 4x3 keypad
2022-06-11 config for encoder direction
2022-06-11 toggle Direction On Encoder Button Press When Stationary
2022-07-03 fix drop locos
    fix for drop all locos
    add direct cmd 4 = multiplier
    [WiTcontroller.ino, actions.h]
2022-07-03 change Multiple to be two stage
    default x 1
    first press x 2
    second press x 4
    third press x 1
2022-07-04 function button fixes
2022-07-22 bug in the loco length
    [WiTcontroller.ino]
2022-07-24 button config moved to separate file
2022-08-09 bug in the roster selection
    [WiTcontroller.ino]
2023-05-18 Routes List Fixes
    fix for more than 10 routes
    [WiTcontroller.ino, config_keypad_etc.h, static.h]
2023-05-20 support for optional additional buttons
2023-05-28 doco updates
    [WiTcontroller - optional buttons v0.1.fzz, WiTcontroller v0.1.fzz]
2023-05-28 Update WiTcontroller - optional buttons v0.1.fzz
    [WiTcontroller - optional buttons v0.1.fzz]
2023-05-30 doco update
    [WiTcontroller v0.1.fzz]
2023-06-02 rework of the 'extras' menu
    [WiTcontroller.ino, static.h]
2023-06-04 multi-throttle support added
    requires v1.1.0 of WiThrottleProtocol library
2023-06-05 allow encoder button to be configurable
2023-06-05 fix display issue with track power
    [WiTcontroller.ino, static.h]
2023-06-05 bug fix for more than 2 throttles
    [WiTcontroller.ino, static.h]
2023-06-06 EStop current loco action
2023-06-14 show Direct commands after showing the functions
    + start of the work to optionally show the speed as a percent
    [config_buttons - problem.txt]
2023-06-15 display speed and direction of next throttle
    in small text on the screen
    [config_buttons_keep.txt]
2023-06-15 increase size of additional throttle speed and direction
2023-06-16 bug fix for round function
    [WiTcontroller.ino, static.h]
2023-06-16 UI improvements for the for the Next Throttle speed and direction
2023-06-16 fix display of zero speed on next throttle
    [WiTcontroller.ino, static.h]
2023-06-18 dynamically change the number of throttles
    available from the 'extras' menu or as assignable commands
2023-06-28 Change the track power text to a glyph
2023-06-28 UI improvements
    change the power and speed step multiplier indicators to glyphs
2023-07-07 add preference to no auto connect to wiThrottle svr
    - add preference to no auto connect to fist found wiThrottle server
    - fix to add "R" to prefix for DCC-EXS CSs
    [WiTcontroller.ino, static.h]
2023-08-27 leading zero on short addresses
    create an exception for DCC-EX CSs to ignore the leading zero is a long address feature.
    [WiTcontroller.ino, static.h]
2023-11-26 minor bug fixes and code cleanup
    now build in VSC without warnings
    [WiTcontroller.ino, static.h]
2023-12-18 remove uneeded file
    [config_buttons_keep.txt]
2024-02-19 fix problem with wifiTrax
    [WiTcontroller.ino, static.h]
2024-02-26 Change to the fix for the wifiTrax WFD-30
    [WiTcontroller.ino, static.h]
2024-03-18 text, button and display PIN configurations moved to defines that can be overridden in personal config_buttons_etc.h files
2024-03-25 support for 4x4 keypads
    [WiTcontroller - 4x4 keypad, Optional buttons v0.1.fzz]
2024-03-26 Update WiTcontroller - 4x4 keypad, Optional Buttons - pinouts v0.1.png
2024-03-26 fixes for the 4x4 keypad
    [WiTcontroller.ino, static.h]
2024-05-20 support for optionally using a potentiometer (pot) instead of the encoder for the throttle
2024-05-21 support for optionally using a voltage divider to show the battery charge level
2024-05-22 change the battery charge level to an icon/glyph
2024-05-22 add diagram for battery
    [WiTcontroller - Optional battery monitor.fzz]
2024-05-22 change the battery check to once ever 10 seconds
2024-05-22 option to have the battery to show as a percent
2024-05-23 changed option to have the battery to show icon as well as a percent
2024-05-23 Version to 1.53
    Made two changes in main code
    1. Comment out random values when displaying battery percentage
    2.Invert logic for the test to display the battery percentage
2024-05-24 Add support for bare EC11 encoder hardware build
    Add support for bare EC11 encoder hardware build
2024-05-26 added auto deep sleep on low battery
2024-06-02 doco update only
    [WiTcontroller - 4x4 keypad, Optional buttons v0.1.fzz, WiTcontroller - Optional battery monitor.fzz, WiTcontroller - optional buttons v0.1.fzz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]
2024-06-16 ESP32 Board Library problem
    [WiTcontroller.ino, static.h]
2024-06-17 automated fix for the ESP32 Board Library problem
    [WiTcontroller.ino, static.h]
2024-07-30 E_STOP fix, UI Improvements, doco updates
    - Moved the battery position to the top line
    - added an Action to show or hide the battery
    - Added some of the UI improvements from HandCab
    - Fixed the E_STOP VS E_STOP_CURRENT_LOCO. Requires WiThrottleProtocol version 1.1.20 to actually work differently.
    - Updated documentation. (Particularly on the use of the battery)
    [WiTcontroller.ino, actions.h, static.h]
2024-08-03 bug fix when not using the battery test
    [WiTcontroller.ino, static.h]
2024-08-11 ignore broadcast alert "Steal from other WiThrottle or JMRI throttle Required"
2024-08-12 Bug fix - Speed step multiplier not being displayed
    [WiTcontroller.ino, static.h]
2024-09-19 support user defined menus. Set additional button as latching or non-latching
    - rewrite of the menu code to support user defined menus
    - bug fix for the Edit Consist not working
    - Fix for individual loco direction (facing) changes in a consist.
    - Add support for setting the additional button as latching or no-latching, overriding the WiThrottle defaults. Requires WiThrottleProtocol version 1.1.24.
    [WiTcontroller.ino, static.h]
2024-09-20 bug fix for adding locos greater than 300 and less than 499
    [WiTcontroller.ino, static.h]
2024-09-25 bug fix for functions list & menus closing when the pot value bounces
    [WiTcontroller.ino, static.h]
2024-09-26 MAX_HEARTBEAT_PERIOD added
    New define added for if no response is received from the server in the specified period (milliseconds), shut down. MAX_HEARTBEAT_PERIOD default is 4 minutes = 240000
2024-10-08 update doco for the battery monitor
    [WiTcontroller - Optional battery monitor.fzz]
2024-10-16 heartbeat improvements
    - Add debug level option ``#define DEBUG_LEVEL``
    - A bug in the heartbeat send in the protocol library was fixed at the same time as this release.
    - if heartbeat is enabled, deliberately send the command to server to start it. (I had previously assumed that this was not required.)
    [WiTcontroller.ino, static.h]
2024-11-28 German translations by Bastian Zechendorf
    - German translations by Bastian Zechendorf
    - Made it simpler to change the language
    - Improvements for non-English language display
    - Bug fix. Removed duplicated first entry in the Roster (at the end)
    [WiTcontroller.ino, language_deutsch.h, static.h]
2024-12-01 always send additional CR+LF
    - The additional CR+LF are now sent ahead of all commands to all command stations by default. This was originally only sent for WiFiTrax, but other commercial CSs seem to have the same issue that this resolved. This can be disabled if needed with ``#define SEND_LEADING_CR_LF_FOR_COMMANDS false`` in ``confing_network.h``.
    - Added a message when the server has just connected and is caught up receiving the roster etc. and is unable to process commands yet.
    [WiTcontroller.ino, language_deutsch.h, static.h]
2024-12-12 Bug fix for when a DCC-EX EX-CommandStation has the password changed from the default.
    [WiTcontroller.ino, static.h]
2024-12-14 Show the battery status on the Start, SSID browse, Wit browse and Shutdown screens.
2024-12-15 Made ``RESTORE_ACQUIRED_LOCOS`` default to true
    - Made ``RESTORE_ACQUIRED_LOCOS`` default to true.
    - Added an Extra Menu option to save the current locos
    - Removed the save when deliberately disconnected or slept the device (extra menu ``#96`` or ``#97``)
2025-01-15 Bug fix + new additional button define process
    - New set of defines to allow for an indefinite number of additional buttons. This requires the use of new set of defines that override the old style ones. <br/> At the moment you can only have up to 11 buttons.
    - Bug fix for momentary functions selected from the roster
    [WiTcontroller - 4x4 keypad, Optional buttons - no pullups.fzz, WiTcontroller - Optional battery monitor.fzz, WiTcontroller - optional buttons v0.1.fzz]
2025-01-28 bug fix for when using the Arduino IDE
    [static.h]
2025-02-01 added missing debug messages for the battery
    [Pangodream_18650_CL.cpp, WiTcontroller.ino, static.h]
2025-02-19 cleanup the images
    [WiTcontroller - 3x4 keypad, Optional buttons - pullups.fzz, WiTcontroller - 4x4 keypad, Optional buttons - no pullups.fzz, WiTcontroller - Basic.fzz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]
2025-02-19 other case versions
2025-03-29 Additional actions to change to specific throttle
2025-04-02 Bug fix for some actions
    Bug fix for SPEED_STOP SPEED_UP SPEED_DOWN SPEED_UP_FAST SPEED_DOWN_FAST E_STOP SPEED_MULTIPLIER
    [WiTcontroller.ino, actions.h, static.h]
2025-04-15 country code notes added
    + fix typo in one of the country code definitions
    [static.h]
2025-05-10 Additional button option SLEEP. Will put the ESP32 to sleep. (i.e. turn off)
2025-08-21 encoder debounce notes - no code changes
2025-10-10 markwtech case added
2025-11-19 EStop bug fix
    EStop bug fix suggested by https://github.com/markwtech
    [WiTcontroller.ino, static.h]
2026-01-20 Default to turning off the automatic sleep on low battery
2026-01-21 multiple WiFi changes
    Trying to track down an odd bug on a couple of devices
    [WiTcontroller.ino, static.h]
2026-01-23 If the SSID scan fails...
    If the SSID scan fails, it lets you choose from the list in the config_network.h
    [WiTcontroller.ino, static.h]
2026-01-31 added ENCODER_INVERT_ROTATION_WHEN_REVERSED
2026-02-08 bug fix for the user defined menus
    [static.h]
2026-02-23 DCC-EX guessed password changes
    When tried to connect to a DCC-EX EX-CommandStation it will now try the 'guessed' password on the first attemp. Then, if it fails to connect, it will ask for the password on the second attempt.
    [WiTcontroller.ino, static.h]
2026-03-06 Automatically store passwords
    - Added ``#define ENCODER_SENSITIVITY`` Default is now 85 for the encoder acceleration instead of the previously fixed 100, but can be overridden
    - Added feature to automatically store all entered passwords in non-volatile memory.store all entered passwords in non-volatile memory.
    [WiTcontroller.ino, static.h]
2026-04-04 new example case
2026-04-10 bug fix for 1.110
    [WiTcontroller.ino, static.h]
2026-05-10 DriverD's variation
2026-09-15 fix for CONSIST_RELEASE_BY_INDEX
    This was incorrectly documented as DROP_LOCO_BY_INDEX in
    config_buttons_example.h
    [static.h]
2026-09-19 more on the config buttons generator
2026-09-20 Added example how to change DEVICE_NAME to config_buttons_example.h
2026-09-22 Bug fix. Don't clear the function states when selecting a subsequent loco of a consist
    [WiTcontroller.ino]
2026-11-05 Added scrolling to the Turnout/Points, Routes and Function Labels menus.
    - Added scrolling to the Turnout/Points, Routes and Function Labels menus.
    - New option SHOW_LONGER_ROUTE_AND_TURNOUT_LABELS defaults to false
    - Fixed a quirk with ENCODER_INVERT_ROTATION_WHEN_REVERSED
